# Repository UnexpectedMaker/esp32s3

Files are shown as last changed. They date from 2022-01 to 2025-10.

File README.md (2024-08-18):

# Unexpected Maker - ESP32-S3 Boards 

Assorted files for my ESP32-S3 development boards 













You can find out more about my ESP32-S3 boards at https://esp32s3.com 

# Contents
In this repo you'll find the following items:

## 3D Models
3D STEP files for each of the OMGS3, NanoS3, TinyS3, ProS3 and FeatherS3 boards

## KiCAD 6/7/8 Symbols
KiCAD 6 symbol files for each of the boards that you can use when integrating one of them into one of your PCB designs.
NanoS3 symbol file is for KiCAD 7 or later
OMGS3 symbol file is for KiCAD 8 or later

## KiCAD 6/7 Footprints	
KiCAD 6 footprint files for each of the boards including both SMD and TH versions for the ProS3
NanoS3 footprint file is for KiCAD 7 or later
OMGS3 footprint file is for KiCAD 8 or later

## Schematics
PDF Schematics for each of the OMGS3, NanoS3, TinyS3, ProS3 and FeatherS3 boards

## Pin Reference Cards
Hires pinout reference cards for each of the OMGS3, NanoS3, TinyS3, ProS3 and FeatherS3 boards

# Support Unexpected Maker

I love designing, making, and releasing projects and products that empower others to learn and build amazing things! I do it because I believe it’s important to share knowledge and give back to the community as many have done before me. It helps us all learn and grow.

Please consider supporting me by buying some of my products from:

https://unexpectedmaker.com/shop

Or by buying one of my products on tindie or Lectronz:

https://www.tindie.com/stores/seonr/
https://lectronz.com/stores/unexpectedmaker

Or by becoming a Patron:

https://www.patreon.com/unexpectedmaker

## Unexpected Maker
http://youtube.com/c/unexpectedmaker

http://twitter.com/unexpectedmaker

https://discord.gg/xAHpApP

https://www.facebook.com/unexpectedmaker/

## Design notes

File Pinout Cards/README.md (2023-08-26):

# Pinout Cards - Unexpected Maker - ESP32-S3 Boards 
Hires pinout cards for my ESP32-S3 boards  

You can find out more about my ESP32-S3 boards at https://esp32s3.com 

Artwork and content in this folder is © 2022,2023 Unexpected Maker, all rights reserved.

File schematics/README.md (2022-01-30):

# Schematics - Unexpected Maker - ESP32-S3 Boards 
PDF Schematics for my ESP32-S3 boards  

You can find out more about my ESP32-S3 boards at https://esp32s3.com 

Please refer to the included license.

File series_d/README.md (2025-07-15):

# Unexpected Maker - Series[D]



Assorted files for my new ESP32-S3 Series[D] development boards 









You can find out more about my ESP32-S3 boards at https://esp32s3.com

# Contents
In this repo you'll find the following items:

## 3D Models
3D STEP files for each of the TinyS3[D], ProS3[D], FeatherS3[D] and EdgeS3[D] boards

You'll also find a STEP file for the EdgeS3[D] Reference Carrier board and a STEP for the M.2 connector footprint with the EdgeS3[D] inserted to help line things up.

## Schematics
PDF Schematics for each of the TinyS3[D], ProS3[D], FeatherS3[D] and EdgeS3[D] boards.

## KiCAD (v9)
Symbol and Footprint for EdgeS3[D] and a project folder for the EdgeS3[D] Reference Carrier PCB.

## Pin Reference Cards
Hires pinout reference cards for each of the TinyS3[D], ProS3[D], FeatherS3[D] and EdgeS3[D] boards

# Support Unexpected Maker
I love designing, making, and releasing projects and products that empower others to learn and build amazing things! I do it because I believe it’s important to share knowledge and give back to the community as many have done before me. It helps us all learn and grow.

Please consider supporting me by buying some of my products from:

https://unexpectedmaker.com/shop

Or by buying one of my products on tindie or Lectronz:

https://www.tindie.com/stores/seonr/
https://lectronz.com/stores/unexpectedmaker

Or by becoming a Patron:

https://www.patreon.com/unexpectedmaker

## Unexpected Maker
http://youtube.com/c/unexpectedmaker

http://twitter.com/unexpectedmaker

https://discord.gg/xAHpApP

https://www.facebook.com/unexpectedmaker/

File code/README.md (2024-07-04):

# Code - Unexpected Maker - ESP32-S3 Boards 
Code examples and helper libraries for ESP32-S3 boards

Currently includes:

## CircuitPython
- Shipping files including the CP helper library and code.py

## MicroPython
- Helper library and example code

## Arduino
- A link to the Helper library and example code for the Arduino IDE, to be installed via the library manager 

## PlatformIO
- An example project setup for the FeatherS3 that uses the UM S3 Helper Arduino library to cycle the RGB LED, flash the Blue LED and print out an RGB cycle count to the serial console. 

You can find out more about my ESP32-S3 boards at https://esp32s3.com 

Please refer to the included license.

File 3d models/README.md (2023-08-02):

# 3D models - Unexpected Maker - ESP32-S3 Boards 
3D STEP models and reference images of my ESP32-S3 boards  

You can find out more about my ESP32-S3 boards at https://esp32s3.com 

Artwork and content in this folder is (c)2022,2023 Unexpected Maker, all rights reserved.

### NanoS3
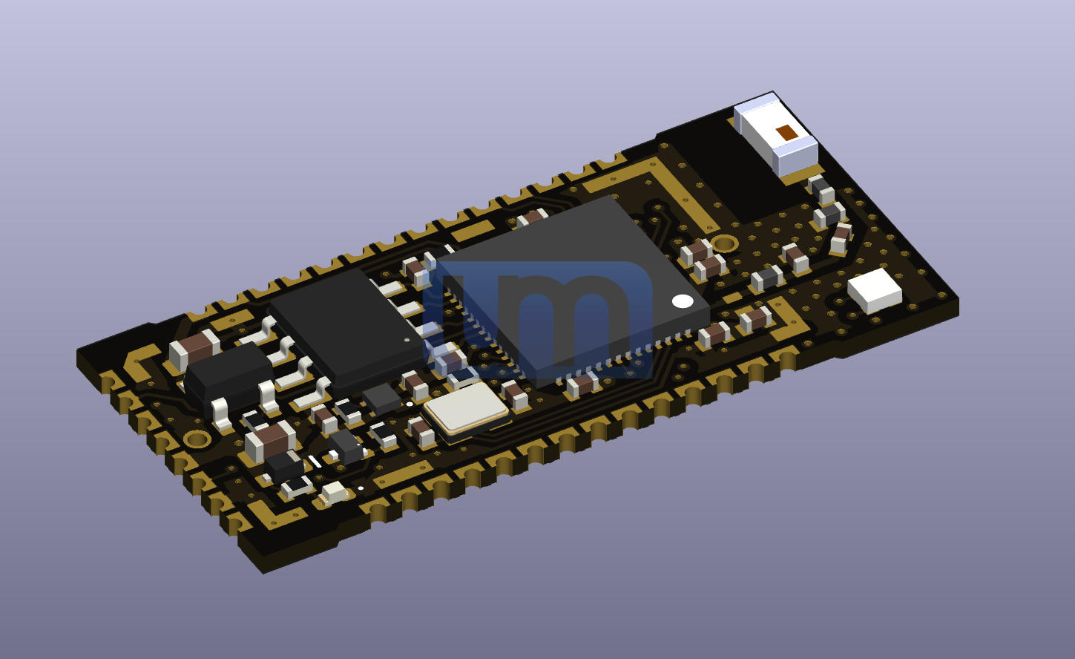
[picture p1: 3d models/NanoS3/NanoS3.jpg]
NanoS3


### TinyS3 & TinyS3 uFL
<div>
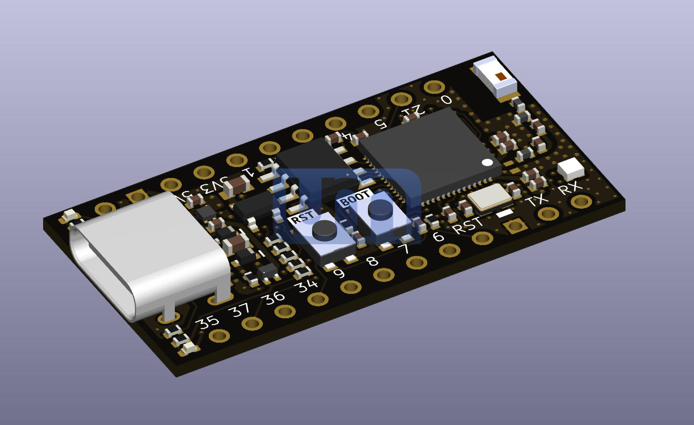
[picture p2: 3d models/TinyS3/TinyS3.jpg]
TinyS3
    
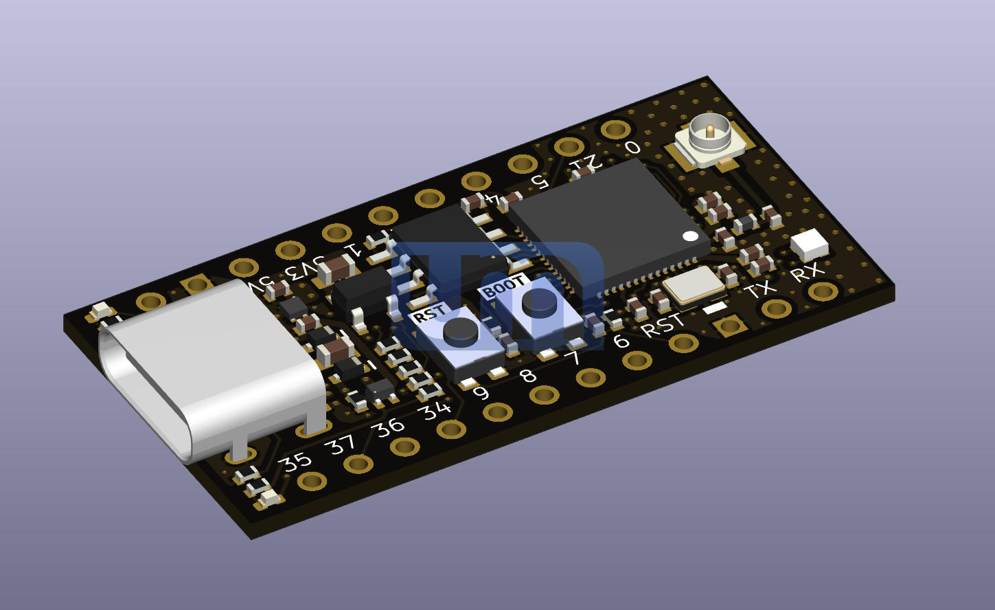
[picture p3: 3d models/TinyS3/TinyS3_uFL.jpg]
TinyS3 uFL
    
</div>

### ProS3 & ProS3 uFL
<div>
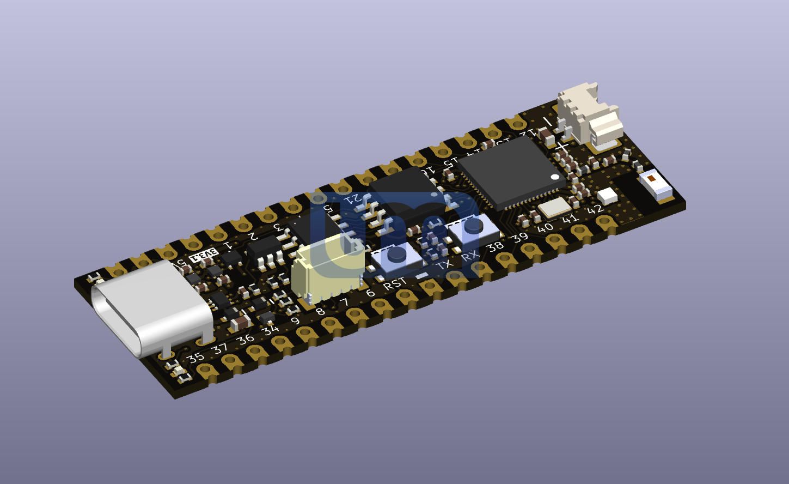
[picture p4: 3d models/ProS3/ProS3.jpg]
ProS3
    
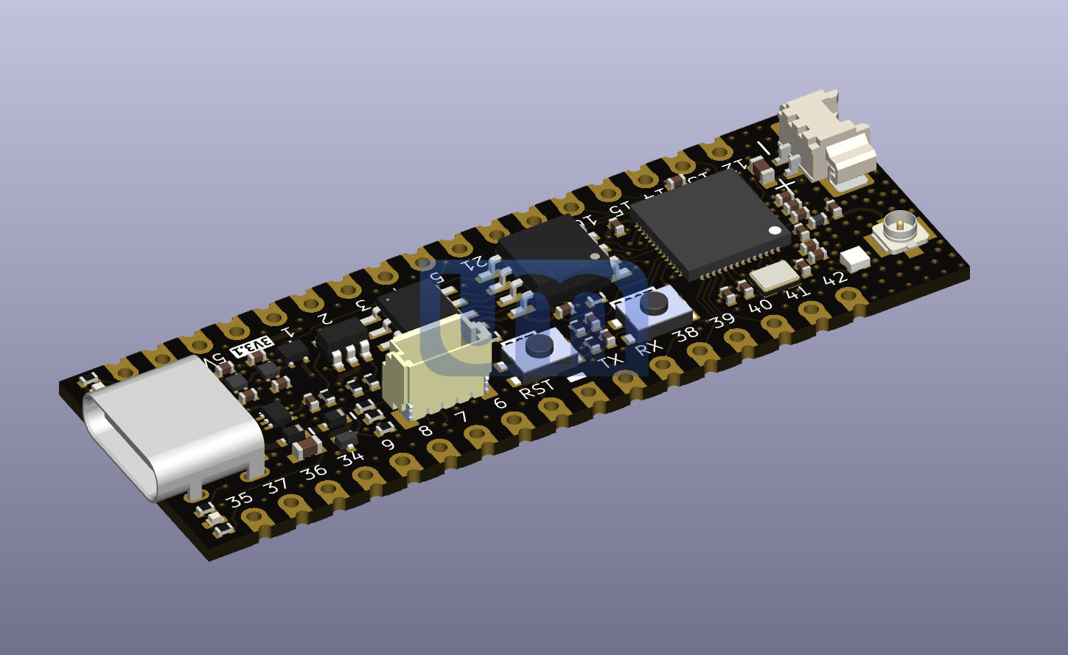
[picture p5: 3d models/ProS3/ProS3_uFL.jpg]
ProS3 uFL
    
</div>

### FeatherS3 & FeatherS3 uFL
<div>
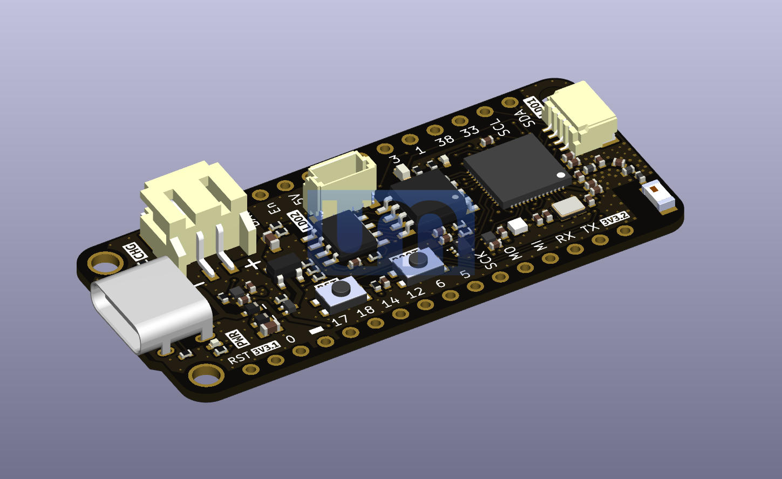
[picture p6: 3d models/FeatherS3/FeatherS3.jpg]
FeatherS3
    
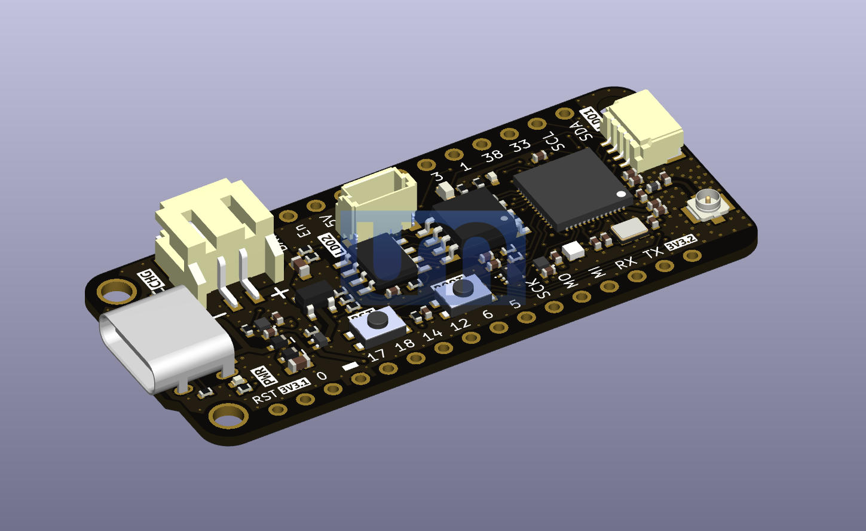
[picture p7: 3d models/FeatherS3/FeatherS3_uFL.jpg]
FeatherS3 uFL
    
</div>

### NanoS3 Carrier
<div>
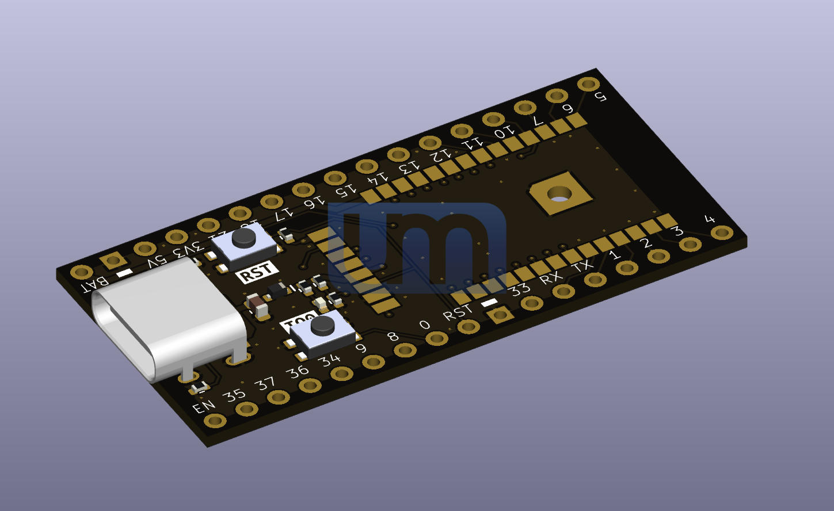
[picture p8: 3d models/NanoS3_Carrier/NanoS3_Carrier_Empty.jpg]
NanoS3 Carrier Empty
    
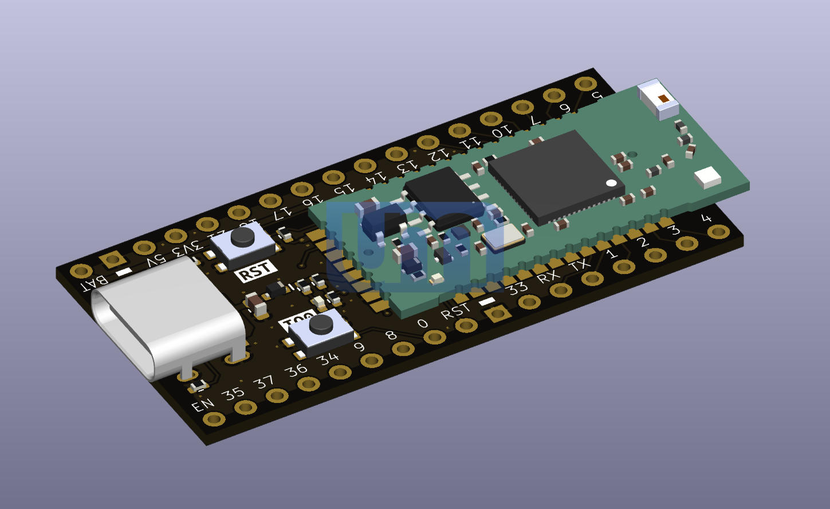
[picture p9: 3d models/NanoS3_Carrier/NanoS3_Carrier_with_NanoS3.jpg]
NanoS3 Carrier with NanoS3
    
</div>

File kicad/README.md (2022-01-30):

# KiCAD Footprints - Unexpected Maker - ESP32-S3 Boards 
KiCAD Footprints for my ESP32-S3 boards  

You can find out more about my ESP32-S3 boards at https://esp32s3.com 

Please refer to the included license.

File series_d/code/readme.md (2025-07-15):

# Code - Unexpected Maker - Series[D] Boards 
Code examples, shipping files and helper libraries for Series[D] boards

Currently includes:

## CircuitPython
Shipping files includes the Circ uitPython helper library and code.py, for each board, plus a `lib` folder populated with the requirements for the `Adafruit MAX17048` Battery FG IC library.

CircuitPython support for EdgeS3[D] (that the EdgeS3[D] ships with) has been PR'd and merged into the CircuiPython repo for a future release.

There are no Series[D] board specific CircuitPython builds for TinyS3[D], ProS3[D] and FeatherS3[D] - They use their origional non Series[D] board CircuitPython builds.

Due to this, not every IO used on a Series[D] board is available in the `boards` import, but all IO can be accessed using `microcontroller.pin`, for example, to access IO11 on the ProS3 buildind running on the ProS3[D], you use the following syntax:

``` python
# Setup the RF switch pin
ant_selection = DigitalInOut(microcontroller.pin.GPIO11)
ant_selection.direction = Direction.OUTPUT
```

## MicroPython
MicroPython builds for TinyS3[D], ProS3[D] and FeatherS3[D] use the origional TinyS3, ProS3 and FeatherS3 builds available at [micropython.org](https://micropython.org/download/?vendor=Unexpected%20Maker)

Helper libraries and example code wil be available soon.

## Arduino
Check the Arduino folder for a link to the Series[D] Helper library and example code for the Arduino IDE, to be installed via the library manager 

## PlatformIO
Soon!

You can find out more about my Series[D] boards at https://esp32s3.com 

Please refer to the included license.

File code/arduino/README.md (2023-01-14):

# Unexpected Maker ESP32-S3 Arduino Helper Library

This is the [helper library](https://github.com/UnexpectedMaker/esp32s3-arduino-helper) for all the Unexpected Maker [ESP32-S3 boards](https://esp32s3.com).

Examples can be found in the [examples directory](https://github.com/UnexpectedMaker/esp32s3-arduino-helper/tree/main/examples), these can also be loaded from the examples menu in the Arduino IDE.

## Installation

Please download the library called `UMS3 Helper` via the Arduino Library Manager.

## List of functions

```c++

// Initializes all UM board peripherals
void begin();

// Set LDO2 on or off (ProS3 and FeatherS3 only)
void setLDO2Power(bool on);

// Set neopixel power on or off (On ProS3 and Feather it sets LDO2 on)
void setPixelPower(bool on);

// Set neopixel color
void setPixelColor(uint8_t r, uint8_t g, uint8_t b);
void setPixelColor(uint32_t rgb);

// Set neopixel brightness
void setPixelBrightness(uint8_t brightness);

// Pack r,g,b (0-255) into a 32bit rgb color
static uint32_t color(uint8_t r, uint8_t g, uint8_t b);

// Convert a color wheel angle (0-255) to a 32bit rgb color
static uint32_t colorWheel(uint8_t pos);

// Set the blue LED on or off (FeatherS3 only)
void setBlueLED(bool on);

// Toggle the blue LED (FeatherS3 only)
void toggleBlueLED();

// Get the battery voltage in volts
float getBatteryVoltage();

// Get the light sensor in volts (0-3.3)
float getLightSensorVoltage();

// Detect if VBUS (USB power) is present
bool getVbusPresent();
```

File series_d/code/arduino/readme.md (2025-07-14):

# Unexpected Maker ESP32-S3 Arduino Helper Library

This is the [helper library](https://github.com/UnexpectedMaker/seriesd_arduino_helper) for all the Unexpected Maker [Series[D] boards](https://esp32s3.com).

Examples can be found in the [examples directory](https://github.com/UnexpectedMaker/seriesd_arduino_helper/tree/main/examples), these can also be loaded from the examples menu in the Arduino IDE.

Examples include switching ANtenna output, Reading the battery, controlling the RGB LED (if one is present on the board)

## Installation

Please download the library called `UM Series[D] Helper` via the Arduino Library Manager.

## List of functions

```c++

// Initializes all UM Series[D] board peripherals
void begin();

// Set LDO2 on or off
// Only available on the ProS3[D] and FeatherS3[D] 
void setLDO2Power(bool on);

// Set RGB LED power on or off (On ProS3[D] and FeatherS3[D] it sets LDO2 on)
// Not available on the EdgeS3[D] 
void setPixelPower(bool on);

// Set RGB LED color
// Not available on the EdgeS3[D] 
void setPixelColor(uint8_t r, uint8_t g, uint8_t b);
void setPixelColor(uint32_t rgb);

// Set RGB LED brightness
// Not available on the EdgeS3[D] 
void setPixelBrightness(uint8_t brightness);

// Pack r,g,b (0-255) into a 32bit rgb color
static uint32_t color(uint8_t r, uint8_t g, uint8_t b);

// Convert a color wheel angle (0-255) to a 32bit rgb color
static uint32_t colorWheel(uint8_t pos);

// Set the blue LED on or off
// Only available on the FeatherS3[D]
void setBlueLED(bool on);

// Get the light sensor in volts (0-3.3)
// Only available on the FeatherS3[D]
float getLightSensorVoltage();

// Toggle the blue LED
// Only available on the FeatherS3[D]
void toggleBlueLED();

// Get the battery voltage in volts
// This function gets the voltage from the MAX17048
float getBatteryVoltage();

// Detect if VBUS (USB power) is present
// Not available on the EdgeS3[D] 
bool getVbusPresent();

// Set the RF Switch to external antenna
void setAntennaExternal(bool state);
```

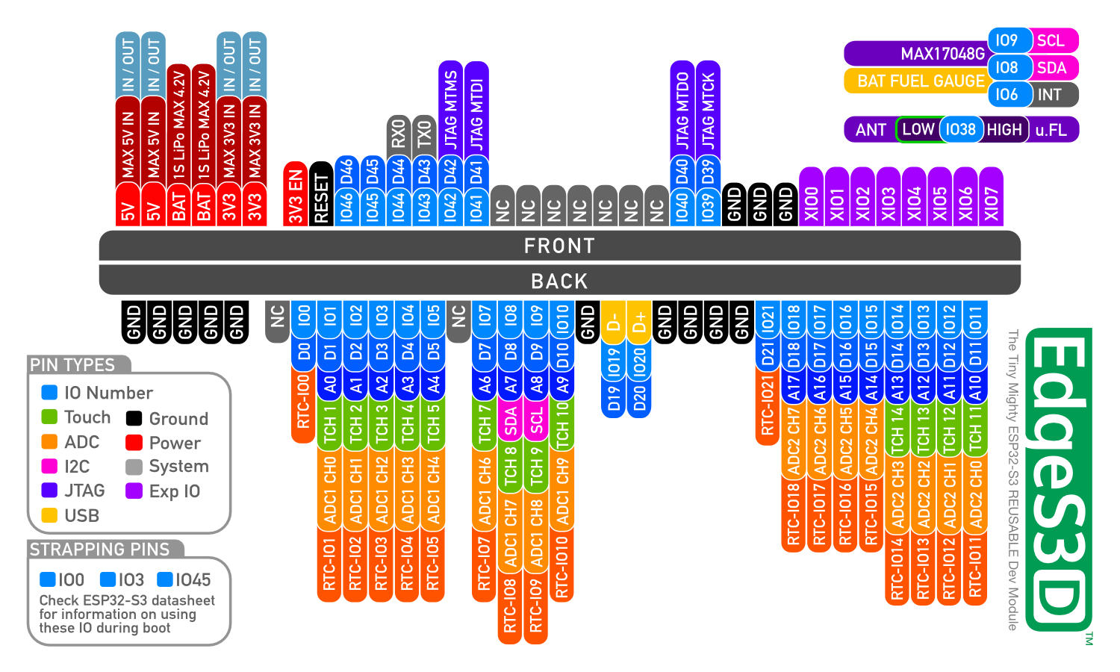
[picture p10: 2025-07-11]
series_d/pinout_cards/edges3d_pinout.jpg

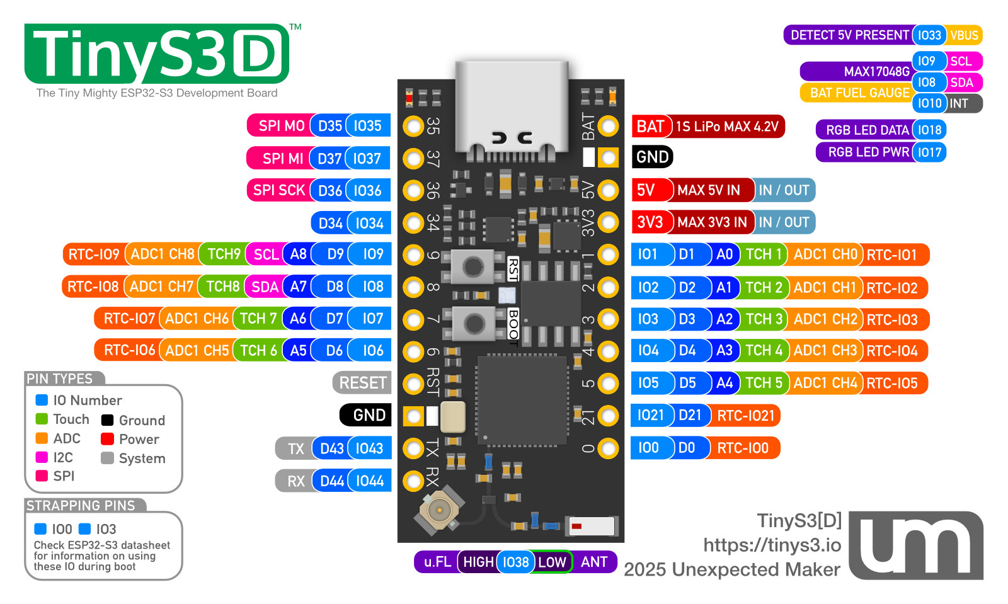
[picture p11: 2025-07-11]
series_d/pinout_cards/tinys3d_pinout.jpg

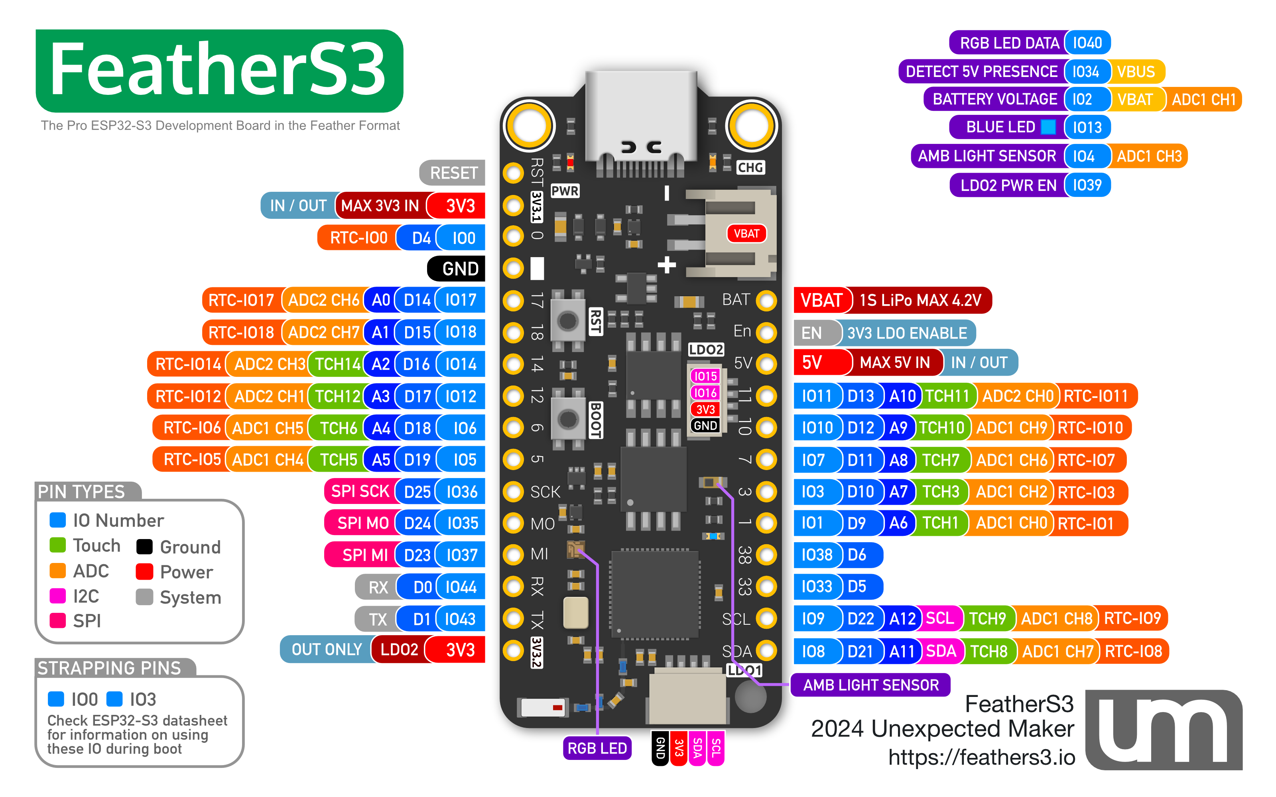
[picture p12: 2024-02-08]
Pinout Cards/FeatherS3_Pin_Reference.png

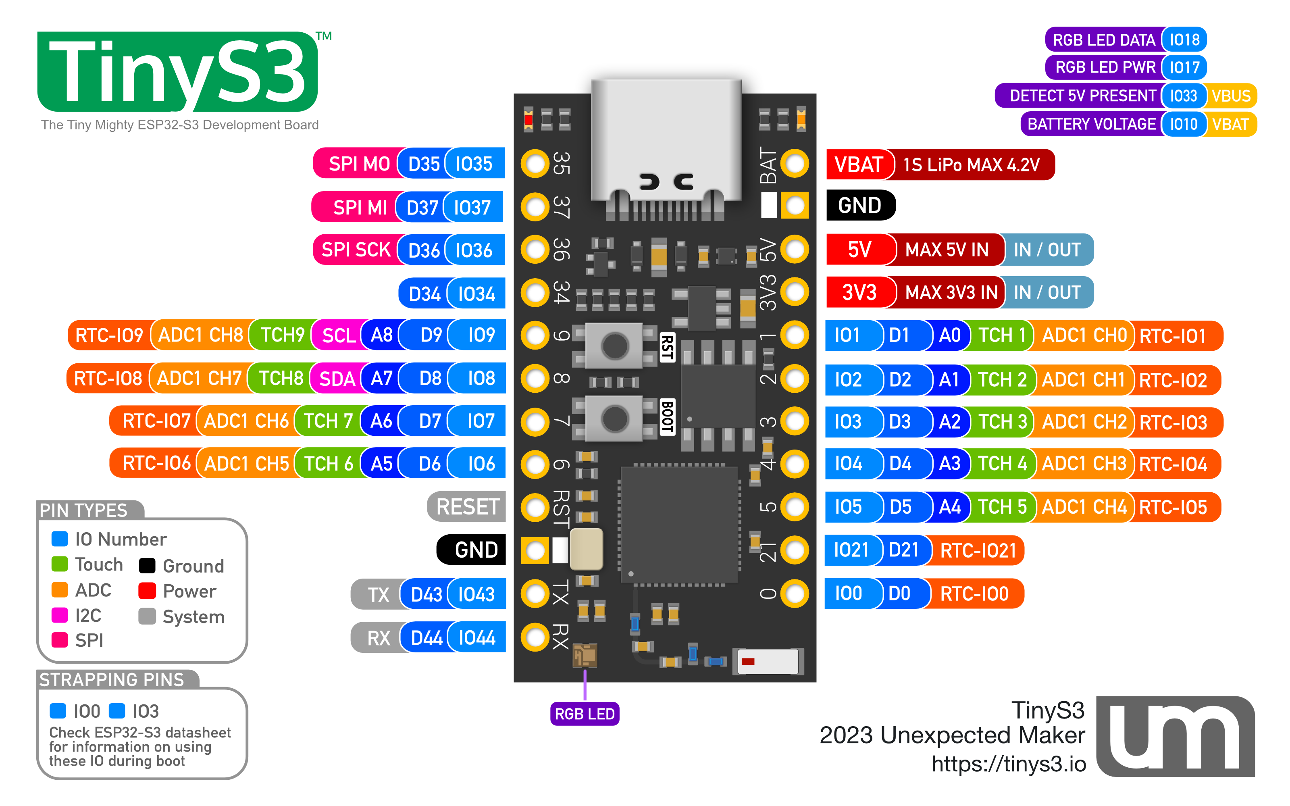
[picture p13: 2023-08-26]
Pinout Cards/TinyS3_Pin_Reference.png

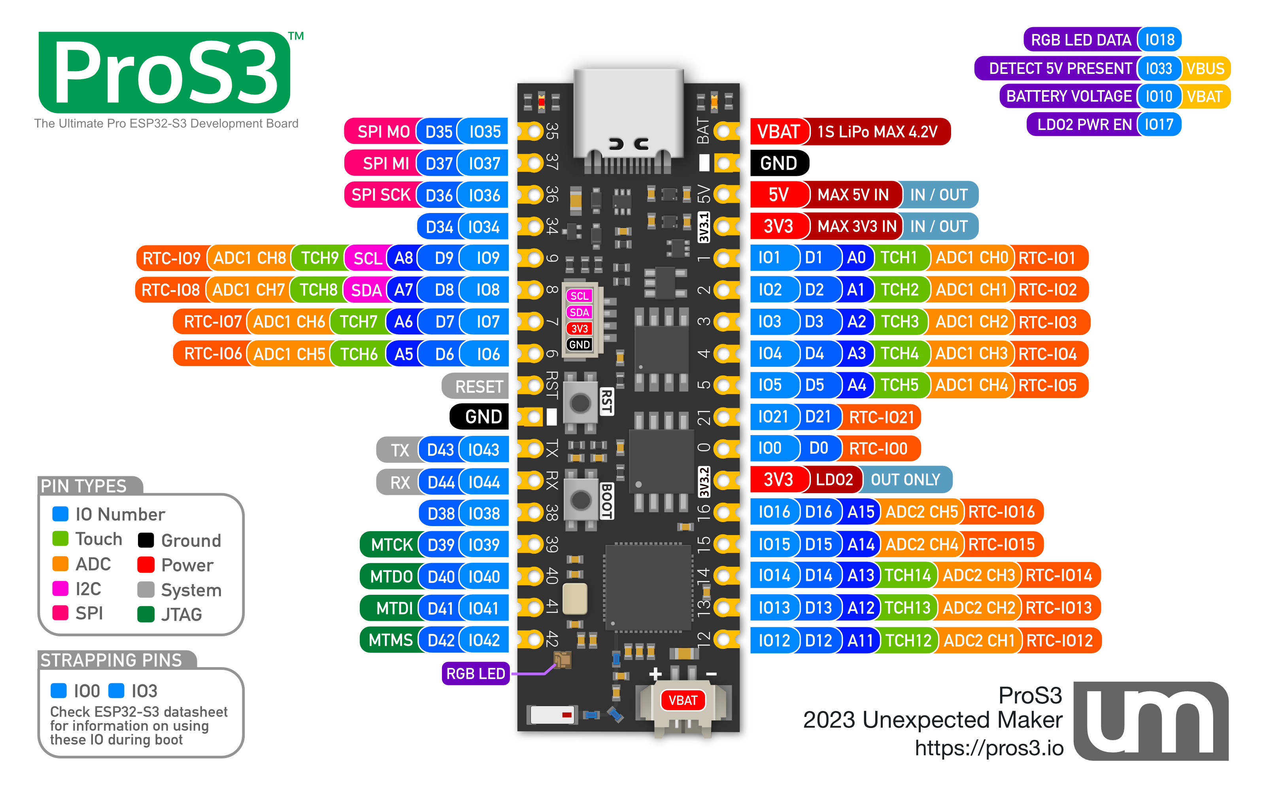
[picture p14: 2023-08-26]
Pinout Cards/ProS3_Pin_Reference.png

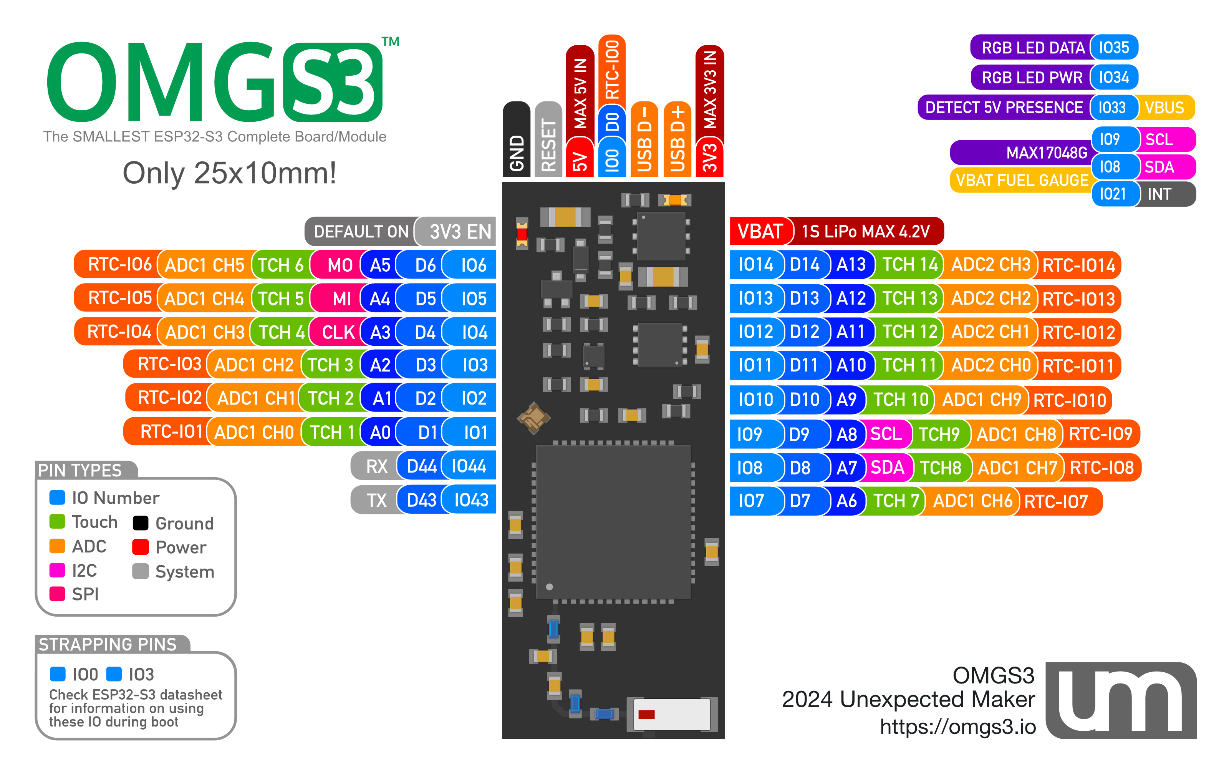
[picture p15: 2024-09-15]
Pinout Cards/OMGS3_Pin_Reference.png

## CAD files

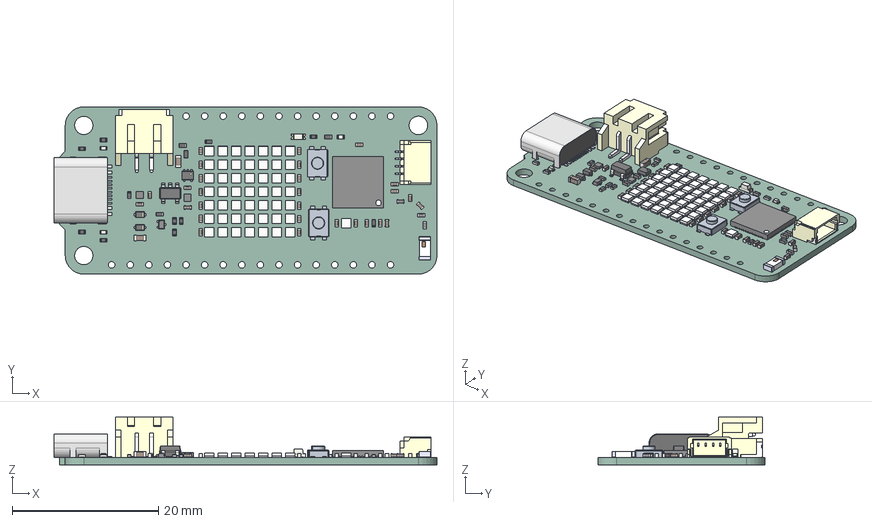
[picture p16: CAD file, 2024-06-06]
3d models/FeatherS3Neo/FeatherS3Neo.step
52.3 x 22.9 x 6.55 mm
2450AT18B100E
D_SOD_523 x 2
LED_0402_1005Metric x 3
R_0402_1005Metric x 15
C_0402_1005Metric x 28
SOT_23_5
ESD7C5.0DT5G
APA102 2020 LED v2 x 50
BTN_KMR2_4.6X2.8_HAND v1 x 2
HRO USB-C col 3 v9
LED_0805_2012Metric_Castellated
ESP32-S2
L_0402_1005Metric x 3
C_0603_1608Metric x 2
SM04B-SRSS-TB(LF)(SN)
NCP160AMX280TBG x 2
S2B-PH-SM4-TB(LF)(SN)
SOT_553
FeatherS3 Neo_PCB

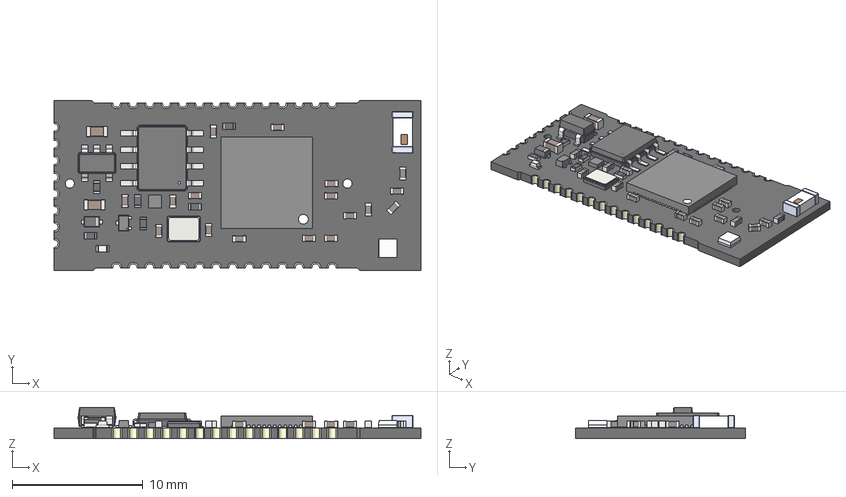
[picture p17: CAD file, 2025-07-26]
3d models/NanoS3/NanoS3 Castellated.step
28.1 x 13.0 x 2.40 mm
NanoS3_2450AT18B PCB

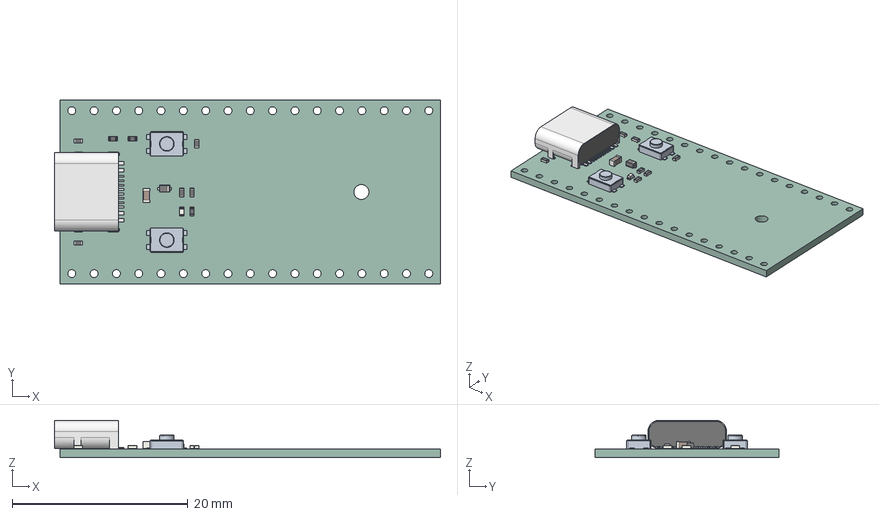
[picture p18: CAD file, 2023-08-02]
3d models/NanoS3_Carrier/NanoS3_Carrier_Empty.STEP
43.9 x 21.0 x 4.24 mm
_autosave-NanoS3_Carrier PCB

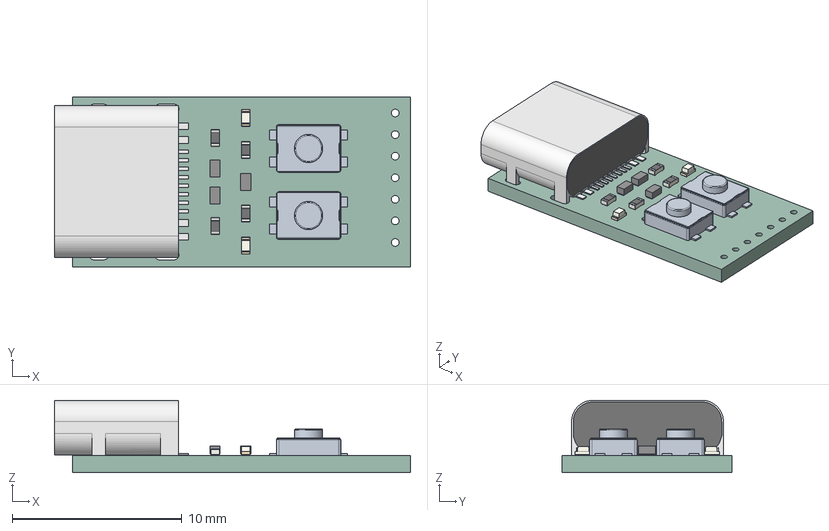
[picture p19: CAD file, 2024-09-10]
3d models/OMGS3/OMGUSB.step
21.0 x 10.0 x 4.26 mm
R_0402_1005Metric x 4
BTN_KMR2_4.6X2.8_HAND v1 x 2
HRO USB-C col 3 v9
TESD5V0L1UC RJG x 3
LED_0402_1005Metric x 2
OMGUSB_P3_PCB

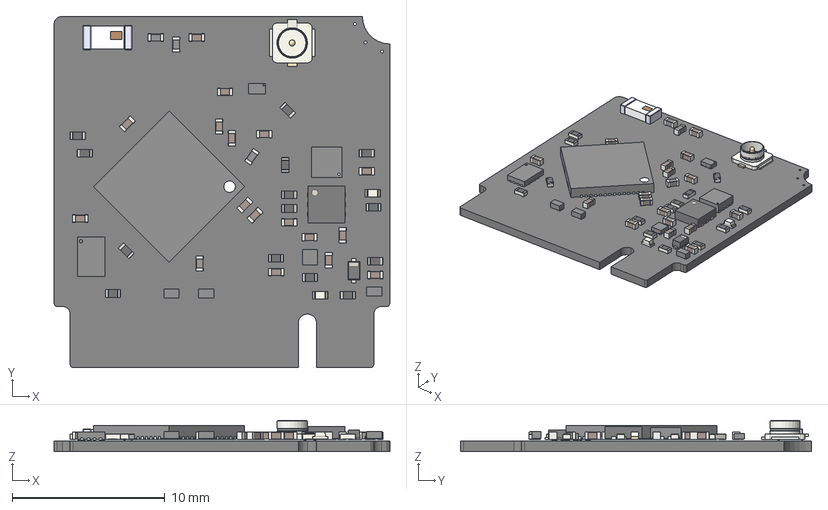
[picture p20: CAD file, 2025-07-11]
series_d/3d models/EdgeS3D.step
22.0 x 23.0 x 2.05 mm
C_0402_1005Metric x 17
U.FL_Hirose_U.FL-R-SMT-1_Vertical
BGS12WN6E6327XTSA1
L_0402_1005Metric x 3
R_0402_1005Metric x 14
TVS_DFN1006 x 3
LED_0402_1005Metric x 2
NCP170AMX170TCG
FXL6408UMX
D_SOD-523
2450AT18B100E--3DModel-STEP-269445
TDFN-6-1EP_2.5x2.5mm_P0.65mm_EP1.3x2mm
MAX17048G-T10
ESP32_S2--3DModel-STEP-1
EdgeS3_Dual_R1_PCB

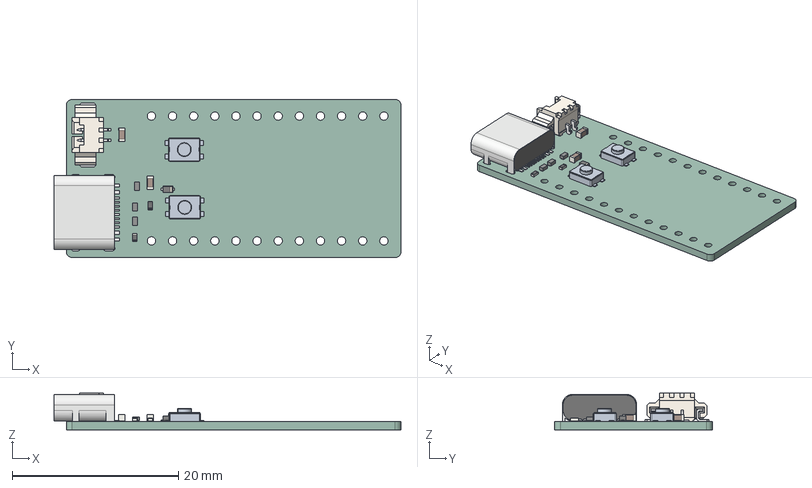
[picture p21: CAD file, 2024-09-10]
3d models/OMGS3/OMGS3_Carrier.step
41.7 x 19.0 x 4.40 mm
C_0603_1608Metric x 2
PICOBLADE v1
BTN_KMR2_4.6X2.8_HAND v1 x 2
R_0402_1005Metric x 2
TESD5V0L1UC RJG x 3
HRO USB-C col 3 v9
D_SOD_523
OMGS3_Carrier_R1_PCB

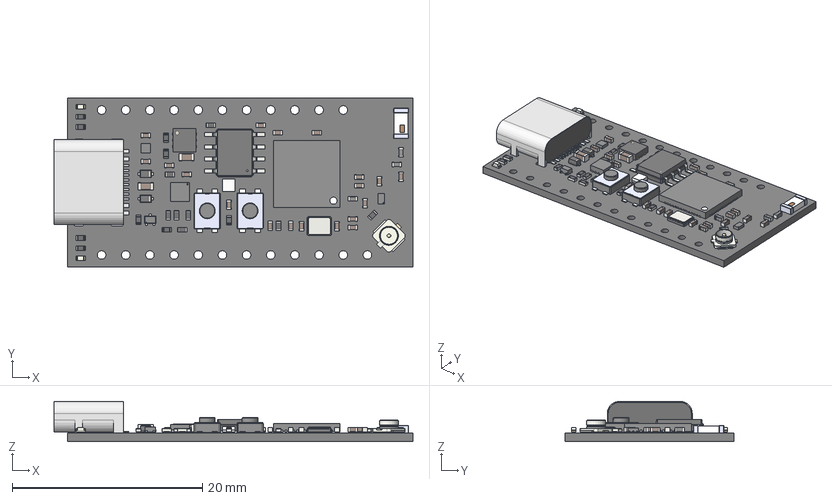
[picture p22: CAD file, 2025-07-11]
series_d/3d models/TinyS3D.step
37.7 x 17.8 x 4.21 mm
R_0402_1005Metric x 17
C_0402_1005Metric x 19
TDFN-6-1EP_2.5x2.5mm_P0.65mm_EP1.3x2mm
L_0402_1005Metric x 3
KMR221GLFS--3DModel-STEP-56544 v3 x 2
U.FL_Hirose_U.FL-R-SMT-1_Vertical
BGS12WN6E6327XTSA1
LED_0402_1005Metric x 2
MAX17048G-T10
SOT-723
NCP170AMX170TCG
D_SOD-523 x 2
SSOP-8_3.9x5.05mm_P1.27mm
2450AT18B100E--3DModel-STEP-269445
Crystal_SMD_3225-4Pin_3.2x2.5mm_HandSoldering
C_0603_1608Metric x 2
ESP32_S2--3DModel-STEP-1
HIRO-USB-C Fixed Position
TinyS3D_P1_PCB

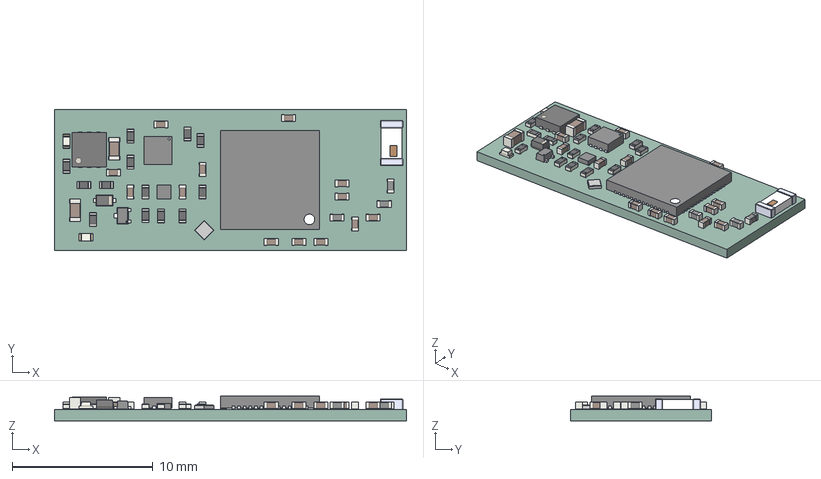
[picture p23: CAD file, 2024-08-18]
3d models/OMGS3/OMGS3.step
25.0 x 10.0 x 1.75 mm
C_0402_1005Metric x 13
L_0402_1005Metric x 3
R_0402_1005Metric x 13
(Unsaved)
TDFN_6_1EP_25x25mm_P065mm_EP13x2mm
2450AT18B100E
LED_0402_1005Metric x 2
MAX17048G+T10
ESD7C5.0DT5G
NCP160AMX280TBG
D_SOD_523
C_0603_1608Metric x 2
ESP32-S2
_autosave-OMGS3_P1_1.27_PCB

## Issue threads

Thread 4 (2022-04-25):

FeatherS3 Pin clarification required from datasheet

sukesh-ak, 2022-04-25:
Are the 2 Stemma QT connectors using the same PINS?

I am trying to use one of them for UART and one for I2C.
Also the labels for Vertical connector is mixed up.

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

UnexpectedMaker, 2022-04-25:
Stemma is only I2C. Yes they share the same I2C pins.

UnexpectedMaker, 2022-04-25:
These are questions for my discord server. Please join there.

Closed 2022-04-25.

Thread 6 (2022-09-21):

404 not found code from link in readme

devoh747, 2022-09-21:
from the readme(https://github.com/UnexpectedMaker/esp32s3/tree/main/code/arduino) "example files"  https://github.com/UnexpectedMaker/esp32s3/blob/main/code/arduino/examples  gives a 404 error as it doesn't exist.

UnexpectedMaker, 2022-09-21:
Fixed, thanks!

Closed 2022-09-21.

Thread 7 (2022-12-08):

D5?

gwolber, 2022-12-08:
Hi, I really love the s3tiny, congratulations on this great work!
However, I encountered a problem: After connecting 5V to the USB power pin on the breakout header, my board cannot be powered over the USB port anymore; D5 seems dead for whatever reason. Could you tell me which type of Z-Diode D5 exactly is? Or is there even a parts list that I did not find?
Thanks, Gerhard

UnexpectedMaker, 2022-12-08:
Oh no! Are you sure you didn't short the pins somehow? You should be able to have the USB connected and the 5V rail connected to external power at the same time.  That's what the back feed diode is there for.
Anyhow, it's a 1A SOD523 Schottky diode, not a Zenner. Any 1A  Schottky will do if you plan on replacing it.

gwolber, 2022-12-09:
Great, thanks!! :)

Closed 2022-12-09.

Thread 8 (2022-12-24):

Backward pins in KiCAD schematic lib for FeatherS3 and TinyS3

username115, 2022-12-24:
All of the pins in the KiCAD schematic library for the FeatherS3 an TinyS3 are backwards. In KiCAD, the little circle is used as the attachment point, and it should be facing outward. Also, the pin labels should be internal to the part.

The ProS3 has its pins in the correct orientation

UnexpectedMaker, 2022-12-24:
That's been fixed, thanks very much for spotting this!

Closed 2022-12-24.

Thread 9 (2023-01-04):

unreliable boot behavior on power up

rottaran, 2023-01-04:
We encountered a timing glitch with one UM FeatherS3 boards. In our hardware, we switch the system on by releasing the Feather's EN pin. Then, quite often the FeatherS3 boots into booloader mode as if the BOOT button was pressed or IO0 pulled to ground. On the oscilloscope it is visible, that the ESP32-S3 chip begins to boot, then activates the internal pullup on IO0. It seems that the voltage is up too late on IO0.

We solved this by adding a 470k resistor from IO0 to 3.3V. Now booting behaves properly.
A larger 4.7uF capacitor from RST to ground did not seem to help.

Is this a known issue? It also never appeared when combined with the Feather OLED Display.

UnexpectedMaker, 2023-01-04:
Are you sure it's not IO47 (SPICLK_P) that's triggering the "enter UF2 bootloader mode" ? It's designed to allow for a double reset press to get into UF2 mode. This is part of the UF2 bootloader code.

Otherwise, it could just be a timing thing, and your fix of putting a weak pull-up on IO0 is the correct solution. I leave IO0 floating by design (the recommended implementation by Espressif) and it's a strapping pin and should not be influenced at boot time, but in your case, the pull-up is fine.

A larger cap on RESET wont make any difference, as the RESET pin on the ESP32 is actually an EN pin, so until EN is high, the ESP32 is off, and therefore wont start to influence IO0. So even a 100000uF cap wont help there ;)

rottaran, 2023-01-13:
Thanks for the feedback! In that case, everything works as designed.

rottaran, 2023-03-03:
Sorry, it's our fault. Due to running out of pins, I attached an 1-wire temperature sensor to the BOOT IO0 pin and forgot the required 4.7k pull-up. Thus, the sensor was delaying the voltage rise during boot and confused the microcontroller.

Closed 2023-01-13.

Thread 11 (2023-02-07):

WiFi stopped working from nowhere

JPZV, 2023-02-07:
Hi! I love this board, and I'm making a smart Xylobands with a fork of [WLED](https://github.com/Aircoookie/WLED/). I don't like the TinyS3 to be very hot while using WiFi so I turn it off after a minute because it's not needed for my project, except for the initial setup.

But right now I have a problem because the WiFi doesn't works at all, and the board overheats a lot, specially with the USB connected (using the Battery will make the board overheat but not that much). At the morning it was working correctly, but from nowhere it stopped to do.

WLED uses the AP Mode, and it doesn't shows up neither on my computer nor on my phone. I also tested a example project from Arduino-esp32 which connects to my network and it also fails (it tries to connect to my network infinitely while another ESP32 would connect almost intermediately)

What can I do? There is no error message apparently so I don't have any clue

~~PS: Viewing the datasheet, there is a capacitor named C5, but on my board that seems to be a resistor, which also is in short (i.e. It has continuity between its terminals). Is it normal? Or is it fried somehow?~~ After viewing the datasheet for others type of ESP32, it seems to be normal to have a zero ohms resistor between the antenna and the ESP32

UnexpectedMaker, 2023-02-08:
Can you join my discord server and post for help in there in the `#um-hardware` help section? That's the best place to get support from me and others in the community.
https://discord.gg/xAHpApP

Thanks :)

Closed 2023-02-08.

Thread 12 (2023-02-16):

Micropython Helper Libraries - get_battery_voltage() results not usable

Hamsanger, 2023-02-16:
Using Micropython V1.19.1+, the implementation of the battery monitor on GPIO2 and get_battery_voltage() produces invalid results.  The default range of the ADC with attenuation of 0dB is only 850mV (refer to the ADC Characteristics in the ESP32-S3 datasheet), so the voltage presented to the ADC from the voltage divider on GPIO2 saturates the count for any usable LiPo voltages unless some input attenuation is used.

I have obtained good results using ATTN_2_5DB and the newer ADC.read_uv() function while scaling the voltage reading using the voltage divider resistor values.  For a FeatherS3 board, the code looks similar to:

```py
# Battery voltage divider.  Voltage seen by the ADC is VBAT * R1 / (R1 + R2)
R1 = 160 # voltage divider R1 in kOhms
R2 = 442 # voltage divider R2 in kOhms

vbat_scale_factor = (R1 + R2) / R1 / 1_000_000 # to convert the microvolt reading to volts

def get_battery_voltage():
    """
    Returns the current battery voltage. If no battery is connected, returns around 4.2V which is the charge voltage
    This is an approximation only, but useful to detect if the charge state of the battery is getting low.
    """
    adc = ADC(Pin(VBAT_SENSE), atten=ADC.ATTN_2_5DB) # Assign the ADC pin to read with nominal 0..1.1V range
    # We are going to read the ADC 10 times and discard the results as we can't guarantee the ADC is calibrated or stable yet after boot. Not sure why we have to do this :(
    for _ in range(10):
        adc.read()
    measuredvbat = adc.read_uv() * vbat_scale_factor
    return round(measuredvbat, 2)
```
As the voltage scaling factor is derived from first principles, the values of R1 and R2 shown can be adjusted to suit other designs.

ShayBox, 2023-07-04:
How does this compare to the current version, it seems to have changed to not use `ADC()`

anglerfish27, 2023-09-28:
FYI. I've used the built in examples with firmware 1.20 (current supported release not the nightly build). It works fine for me. The voltage of the battery when polled is exactly the voltage reading I get from a benchtop multi meter. So if the board says my Lipo battery is at 3.1V I disconnect and check it indeed its right on at 3.1xxxxxx Volts. I'm not doing anything special except running 1.20 official release of MP from their website. Good luck.

I found this to be a very hand feature so I can shutdown the MCU workload when the battery reaches what I decide is too low for that particular set of Lipo 18650's based on manufacturer specs.  Best of luck. Seems to work fine for me. ::shrug::

Closed 2025-08-24.

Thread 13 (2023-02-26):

External Anntena ProS3

osorioen, 2023-02-26:
Hi. I need to connect a external antenna to ProS3 . How can I do it?

UnexpectedMaker, 2023-02-26:
It's not really possible. Even taking off the SMD antenna won't allow you to attach an external antenna.

UnexpectedMaker, 2023-05-11:
Just wanted to let you know I've released new S3 boards with u.FL connectors....
https://unexpectedmaker.com/shop/pros3-ufl

Closed 2023-08-03.

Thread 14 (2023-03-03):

FeatherS3 pins for external 32.768kHz crystal

rottaran, 2023-03-03:
While doing experiments with BLE on battery power, we noticed an unexpectedly high current consumption. This makes the battery connector on the board less useful. With dynamic frequency scaling, modem-sleep and CPU pause, we got down to 25mA average. In order to get to the 2 to 5mA light-sleep mode with running BLE connections, it is necessary to connect a 32.768kHz crystal and respective load capacitors to the XTAL_32K pins.

Sadly, the XTAL_32K seem to be not connected on anything on the UM Feather S3. Maybe it could be a nice feature for future products to at least have unpopulated footprints for the crystal and capacitors on the bottom side of the board.

UnexpectedMaker, 2023-08-03:
Sorry I didn't get around to answering this already :(
IO15/16 that are used for hooking up an external 32K Xtal are already in use on the second STEMMA/QT connector as I2C bus 2, sorry.

rottaran, 2023-08-05:
No problem. I was unaware of the change back then. Seems sensible to separate both I2C busses. Out of curiosity, what speaks against using IO17/IO18 or IO45/IO46 for the STEMMA2 connector?

UnexpectedMaker, 2023-08-06:
Well, IO46 is a strapping IO, so not usable, but ultimately, nothing wrong with other IO for STEMMA2 - but 15/16 is what I chose and it can't be changed now as it's a released design with supporting firmware that initialises those pins as STEMMA/QT #2.

I do custom design works for people needing alterations on my designs - if an external 32k Xtal is something you'd like and it's something you require in quantity, I'm happy to chat about it.

Closed 2023-08-09.

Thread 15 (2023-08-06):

connector lost (LDO2)

CrackXT, 2023-08-06:
Some thing is missing ;)
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

UnexpectedMaker, 2023-08-06:
Fixed, thanks very much :)

Closed 2023-08-06.

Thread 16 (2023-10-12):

Error in schematic ?

eleroy, 2023-10-12:
Hi,

Thank you for your boards, I love them.

I wonder if there is an error in the schematic [here](https://github.com/UnexpectedMaker/esp32s3/blob/main/schematics/schematic-tinys3.pdf).

I'm not the best at electronics but isn't The P-mos T3 used for switching off the battery when connecting the USB upside down ?

Usually for a P-mos, the current is meant to flow from source to drain.

Best,

Edouard.

UnexpectedMaker, 2023-10-12:
The schematic for the power section may look unconventional, but it is correct :)

eleroy, 2023-10-17:
Ah yes, I got it, thanks.

Closed 2023-10-17.

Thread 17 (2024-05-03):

Using the voltage reader function for higher voltages?

anglerfish27, 2024-05-03:
Is it possible to use the code for checking the amount of voltage of the battery to a much higher voltage if you make the appropriate changes in the helper file? Say I wanted to see what the voltage of a 48V battery is, would that work? Would other parts of the code need modification besides the part that sets it to 4.2v currently?

Cheers.

UnexpectedMaker, 2024-05-03:
Absolutely not! You’ll blow up the IO on the ESP32 chip. The voltage divider on the board is there to reduce the voltage going to the IO to make a 4.2V max voltage fit into the ADC range.

Closed 2024-05-13.

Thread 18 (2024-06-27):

Platformio: S3 UM boards.json does not use tinyuf2

Jason2866, 2024-06-27:
@UnexpectedMaker The S3 boards.json currently used in Platformio are not using the tinyuf2 scheme (like in ArduinoIDE).
Example: https://github.com/platformio/platform-espressif32/blob/develop/boards/um_tinys3.json
Is this intended?

It is easy possible to do as done here for an Adafruit board: https://github.com/platformio/platform-espressif32/blob/develop/boards/adafruit_feather_esp32s3_reversetft.json

UnexpectedMaker, 2024-06-27:
Most of my S3 boards were not added by me, but by other people, likely before I added uf2 support.

I'll add it to my list of things to get to, thanks :)

Closed 2025-08-24.

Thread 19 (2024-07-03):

(feature request) - new product - PicoS3; an inside-your-usb-a-port-sized full-featured MCU !

gitcnd, 2024-07-03:
I'm dreaming of the PicoS3 (new invention).

It's half the size of your NanoS3, with USB-A pads on the bottom, and low-profile enough to plug directly in to a USB socket, leaving nothing more than the width of the antenna poking out, beside which is a 4-pin JST SH socket (which can be used for  I²C when plugged in to a host USB device, or which can be used to power the device if it's not connected inside a USB-A socket.

It's so tiny, customers could even "hack it inside" to the plug of an existing cable, without even knowing it's inside there.

It would "expose" as many as possible other useful pins as teeny-tiny solderable points on the underside, which are covered-over with a solder mask (if we want to use them, we need to scrape off the mask first), and the very edge of the connector (below the antenna) exposes enough non-masked contact area pads that sensing a finger-touch on those exposed pins can be managed).

If there's room to cram the WS2812B behind the antenna so we can at least see its glow from inside there, that would be the icing on the minicake !

Closed 2025-08-24.

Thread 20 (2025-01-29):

OMGS3 Power Path missing USB connection?

tylercrumpton, 2025-01-29:
Hiya! First off, thanks so much for sharing these schematics and symbols and part symbols, I've learned a lot for my own personal projects ever since buying some of your FeatherS2's!

Looking at the Power Path on the [schematic for the OMGS3](https://github.com/UnexpectedMaker/esp32s3/blob/main/schematics/schematic-omgs3.pdf), it seems like there is supposed to be an USB power connection to the net attached to the gate of the battery isolation PMOS (T3)? Without it, I don't see how the gate would ever be closed if battery voltage is present.

UnexpectedMaker, 2025-01-29:
There is a USB connection there - looks like I had the label hidden, sorry. I'll fix that and update the schematic when I get a chance.

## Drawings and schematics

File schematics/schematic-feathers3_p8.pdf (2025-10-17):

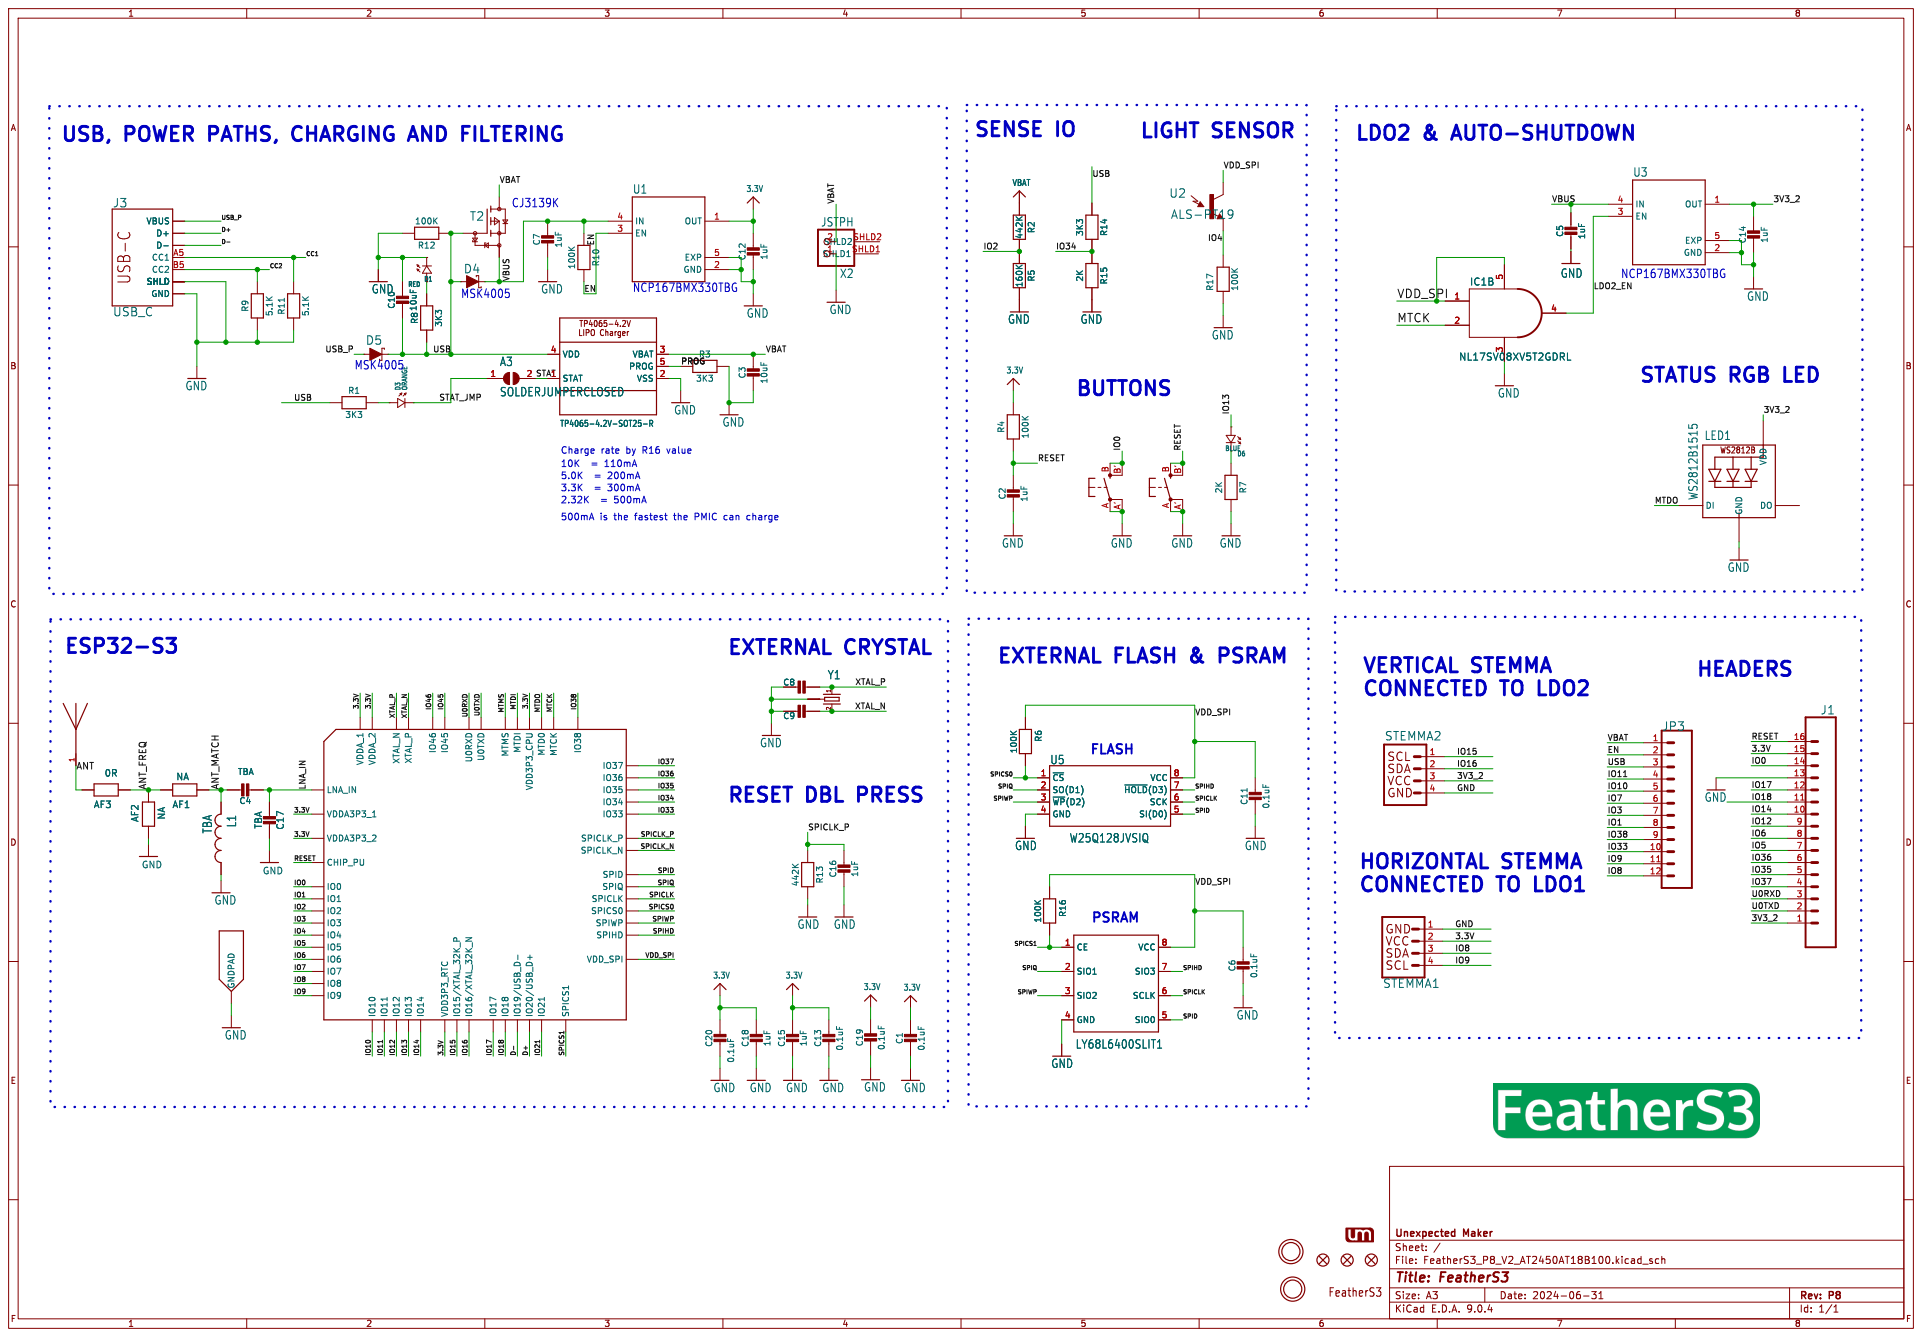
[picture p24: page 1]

500mA is the fastest the PMIC can charge

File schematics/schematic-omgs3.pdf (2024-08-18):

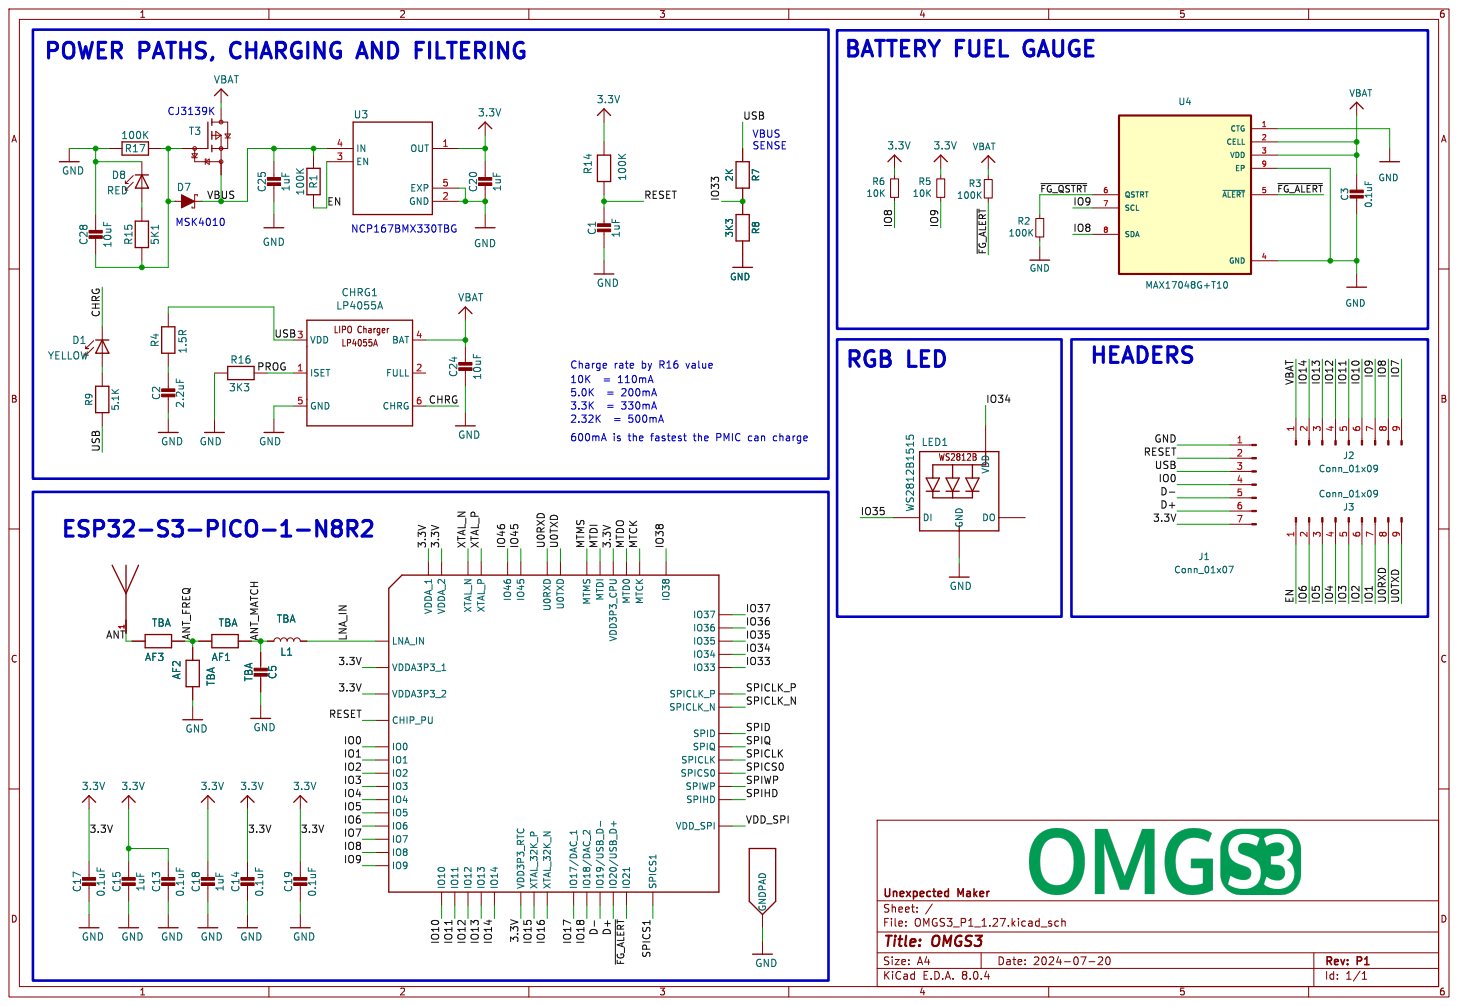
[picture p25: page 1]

POWER PATHS, CHARGING AND FILTERING

600mA is the fastest the PMIC can charge

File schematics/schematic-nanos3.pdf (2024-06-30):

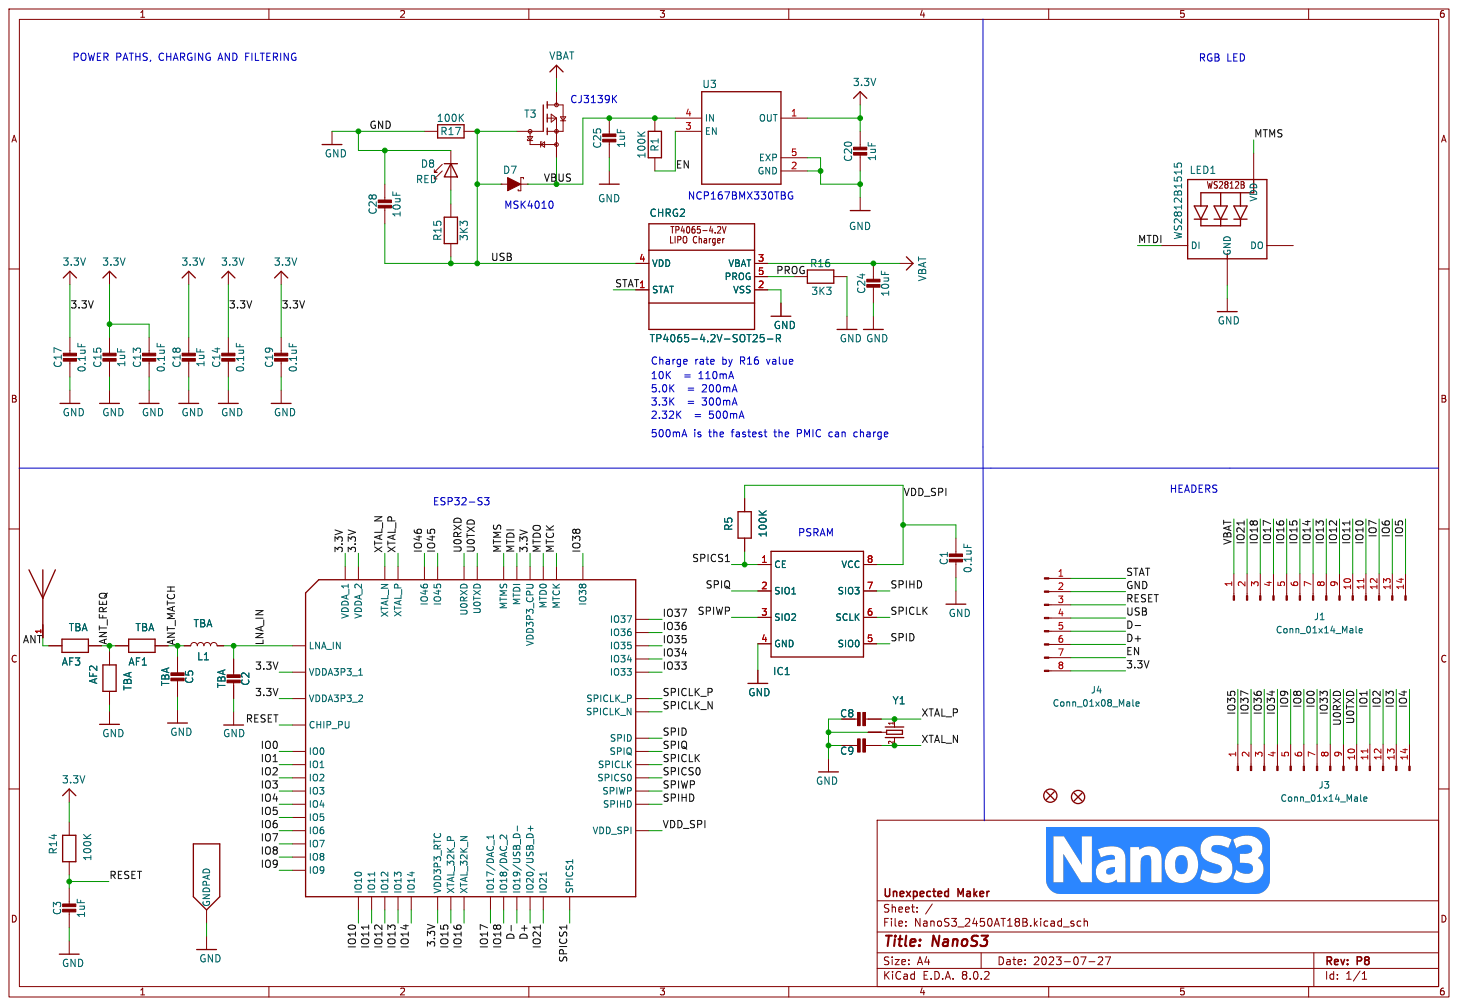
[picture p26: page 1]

POWER PATHS, CHARGING AND FILTERING

500mA is the fastest the PMIC can charge PSRAM

1 2 Y1 CE 1 SIO1 2 SIO2 3 GND 4 SIO0 5 SCLK 6 SIO3 7 VCC 8

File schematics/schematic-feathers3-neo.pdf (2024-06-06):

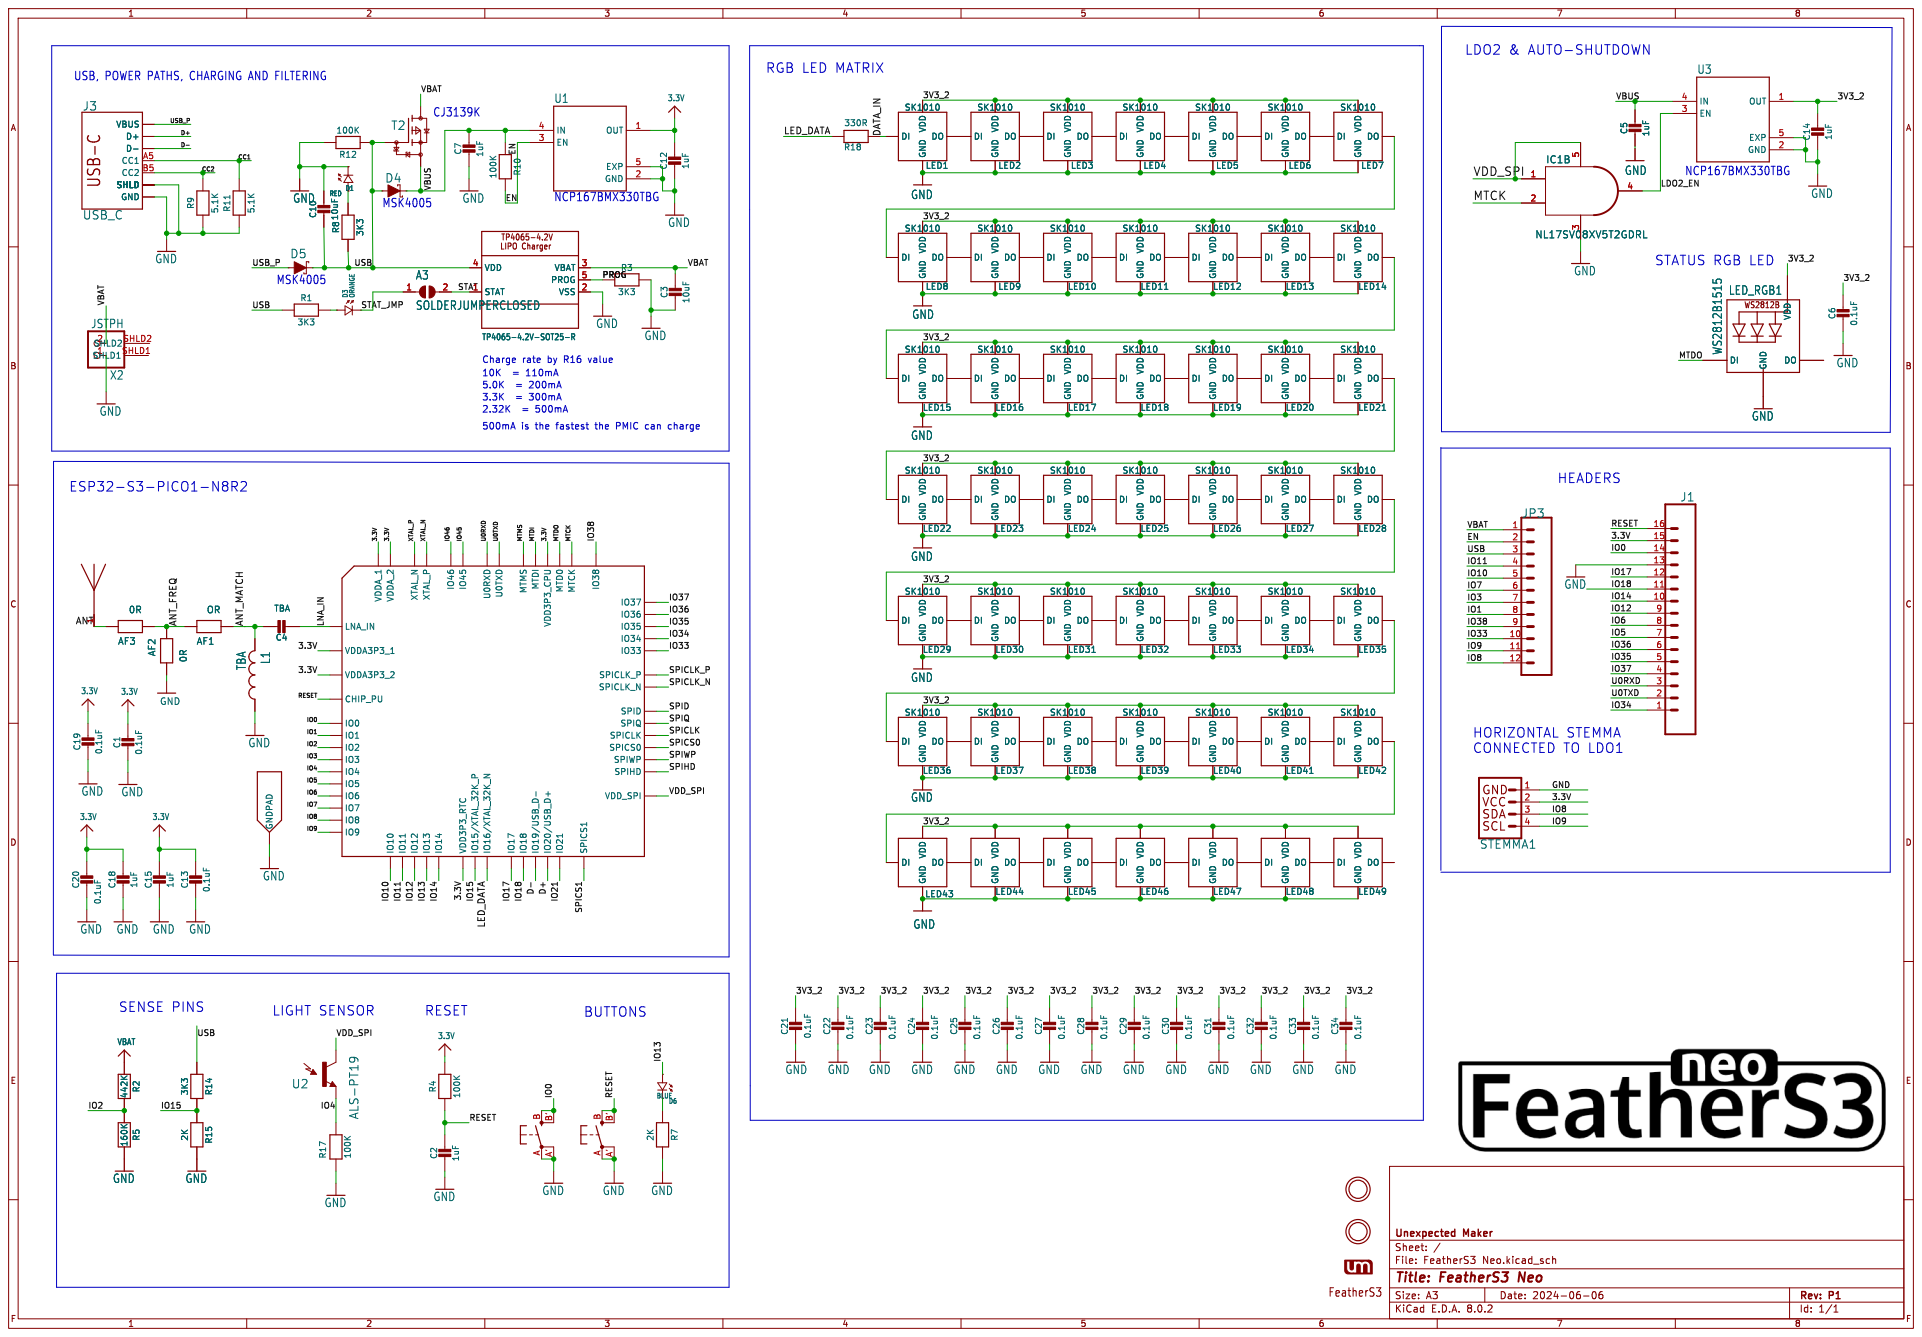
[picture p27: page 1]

USB, POWER PATHS, CHARGING AND FILTERING

5 LED21 SK1010 DI DO GND VDD LED7 SK1010 DI DO GND VDD

500mA is the fastest the PMIC can charge

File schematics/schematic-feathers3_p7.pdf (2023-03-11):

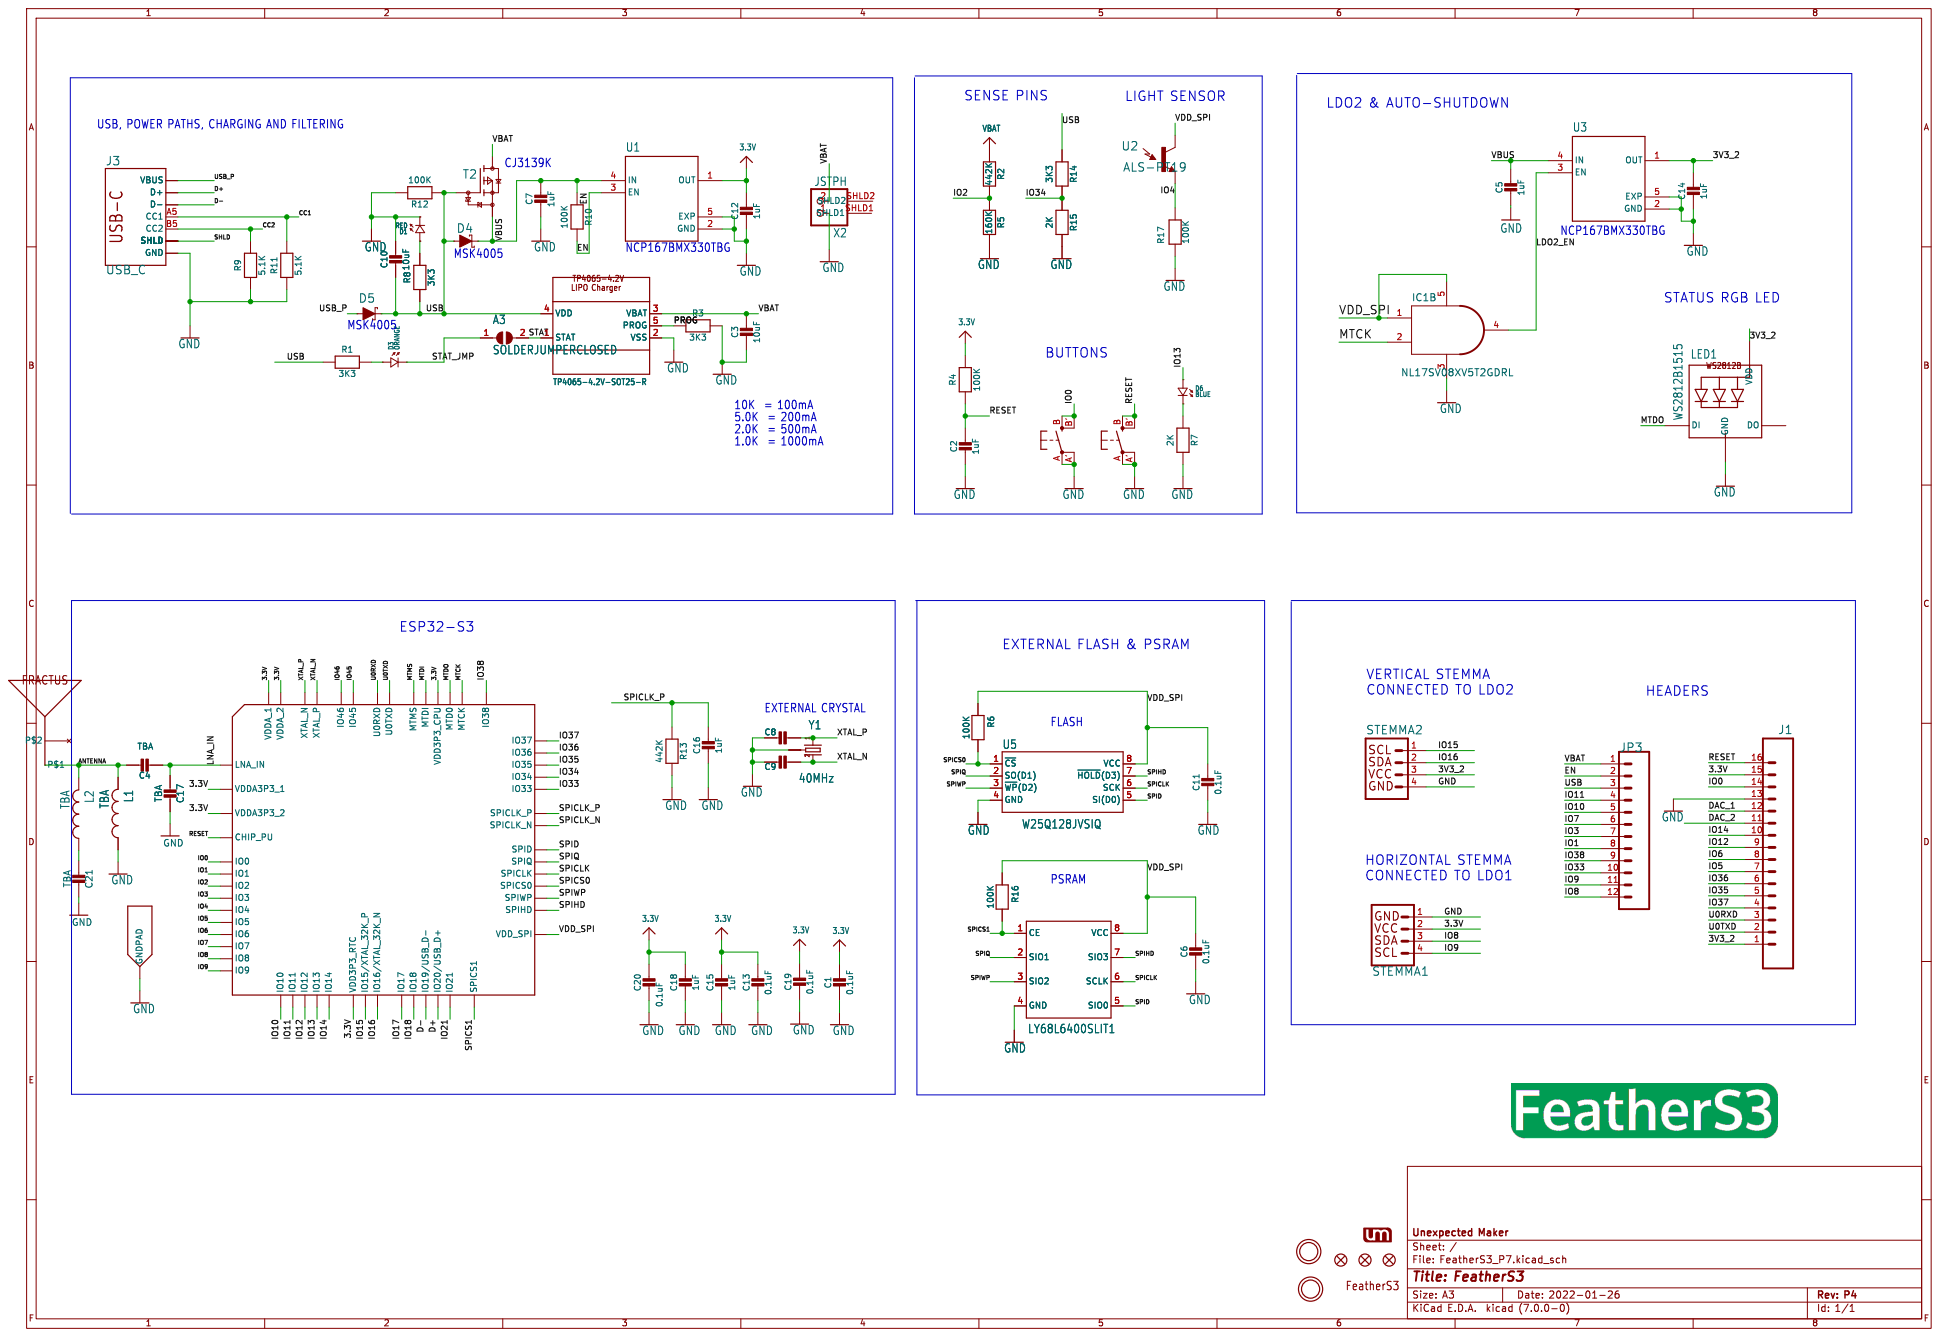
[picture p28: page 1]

VERTICAL STEMMA CONNECTED TO LDO2 PSRAM

File: FeatherS3_P7.kicad_sch Sheet: / Unexpected Maker

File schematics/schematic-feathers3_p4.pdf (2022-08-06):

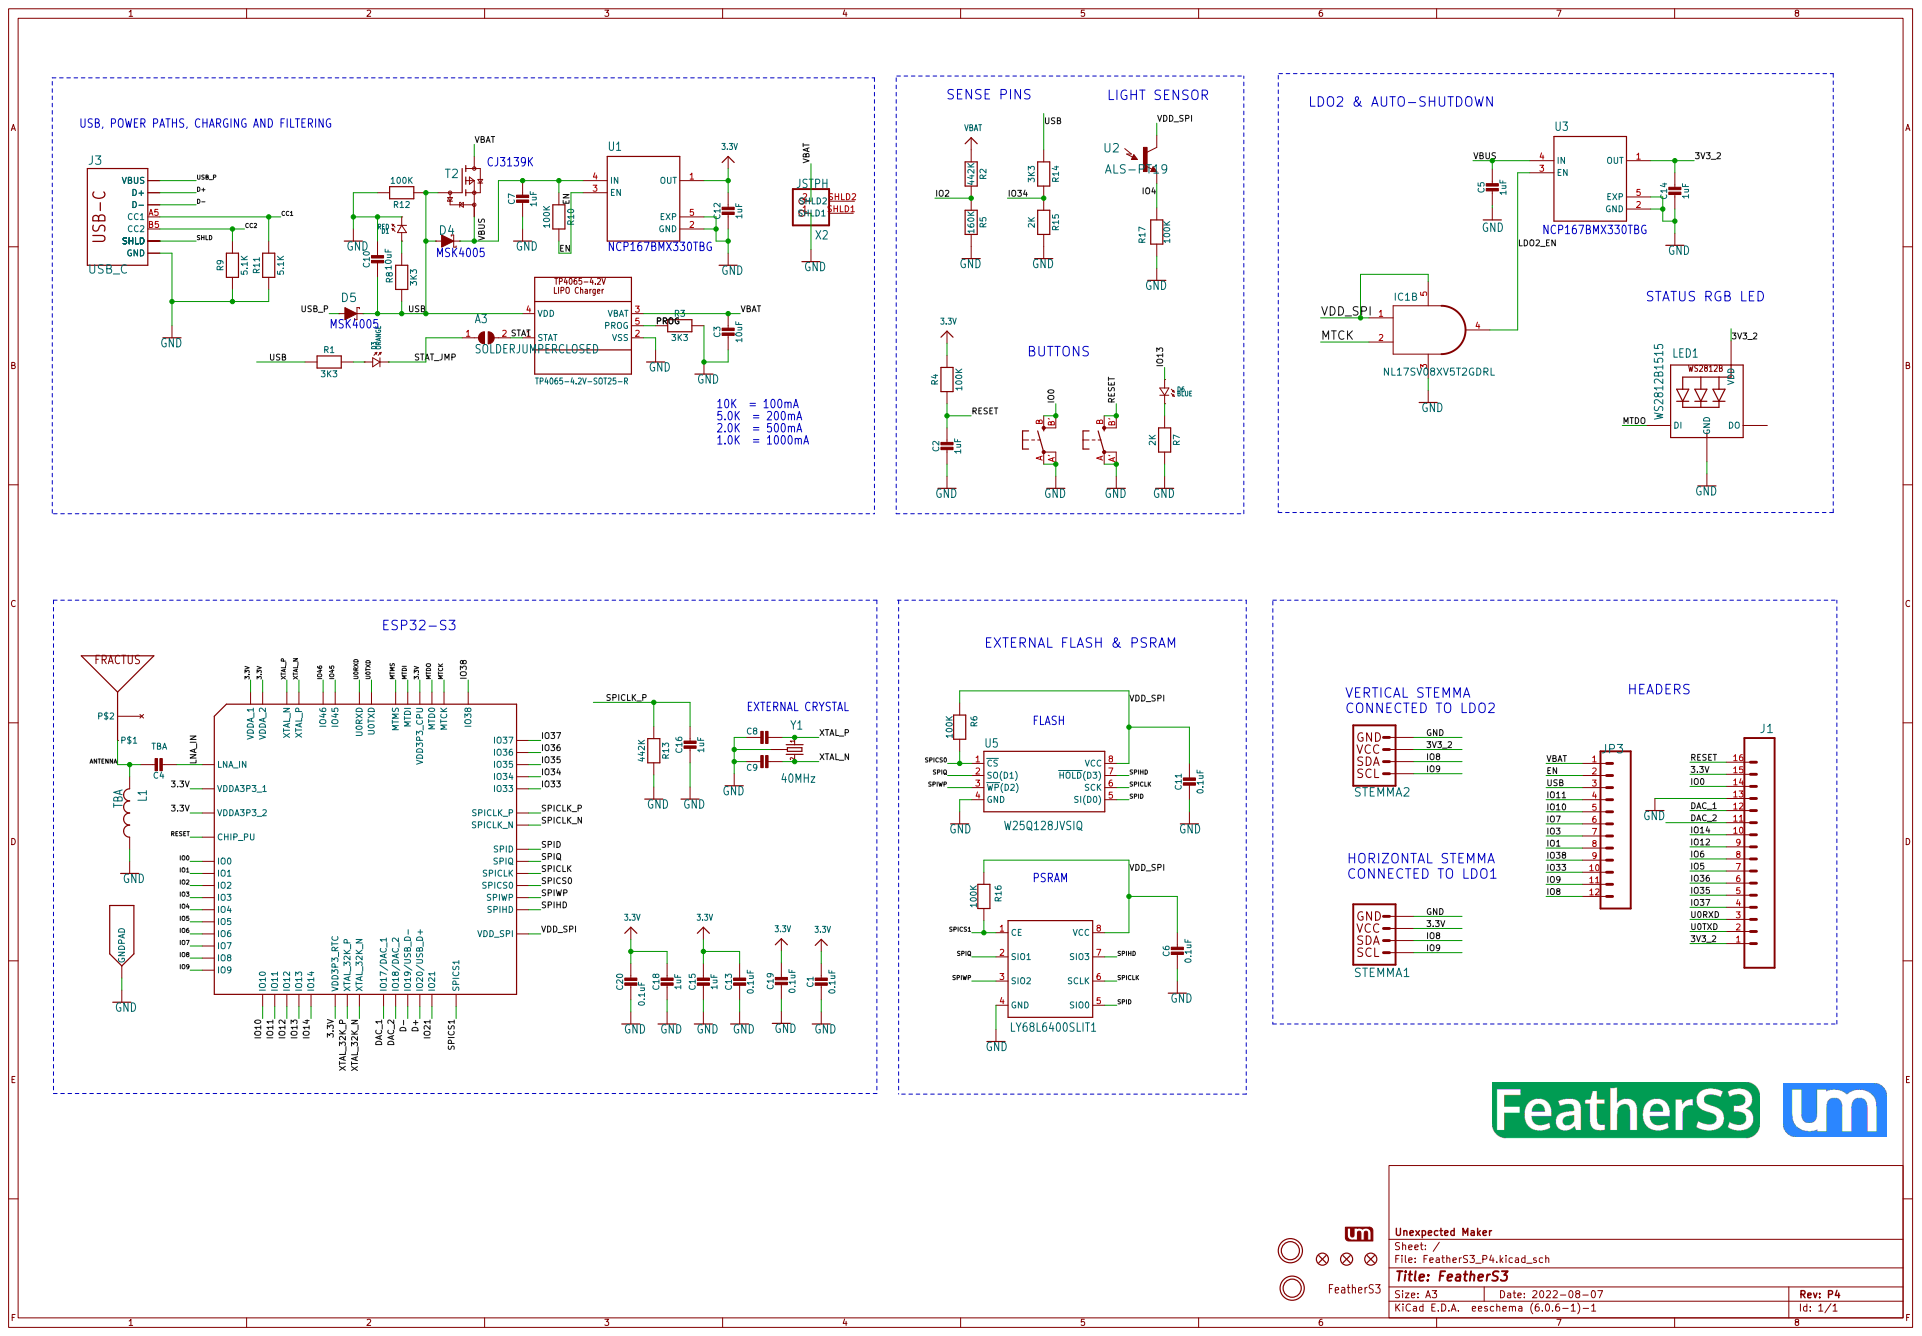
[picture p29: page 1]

USB, POWER PATHS, CHARGING AND FILTERING

File: FeatherS3_P4.kicad_sch Sheet: / Unexpected Maker

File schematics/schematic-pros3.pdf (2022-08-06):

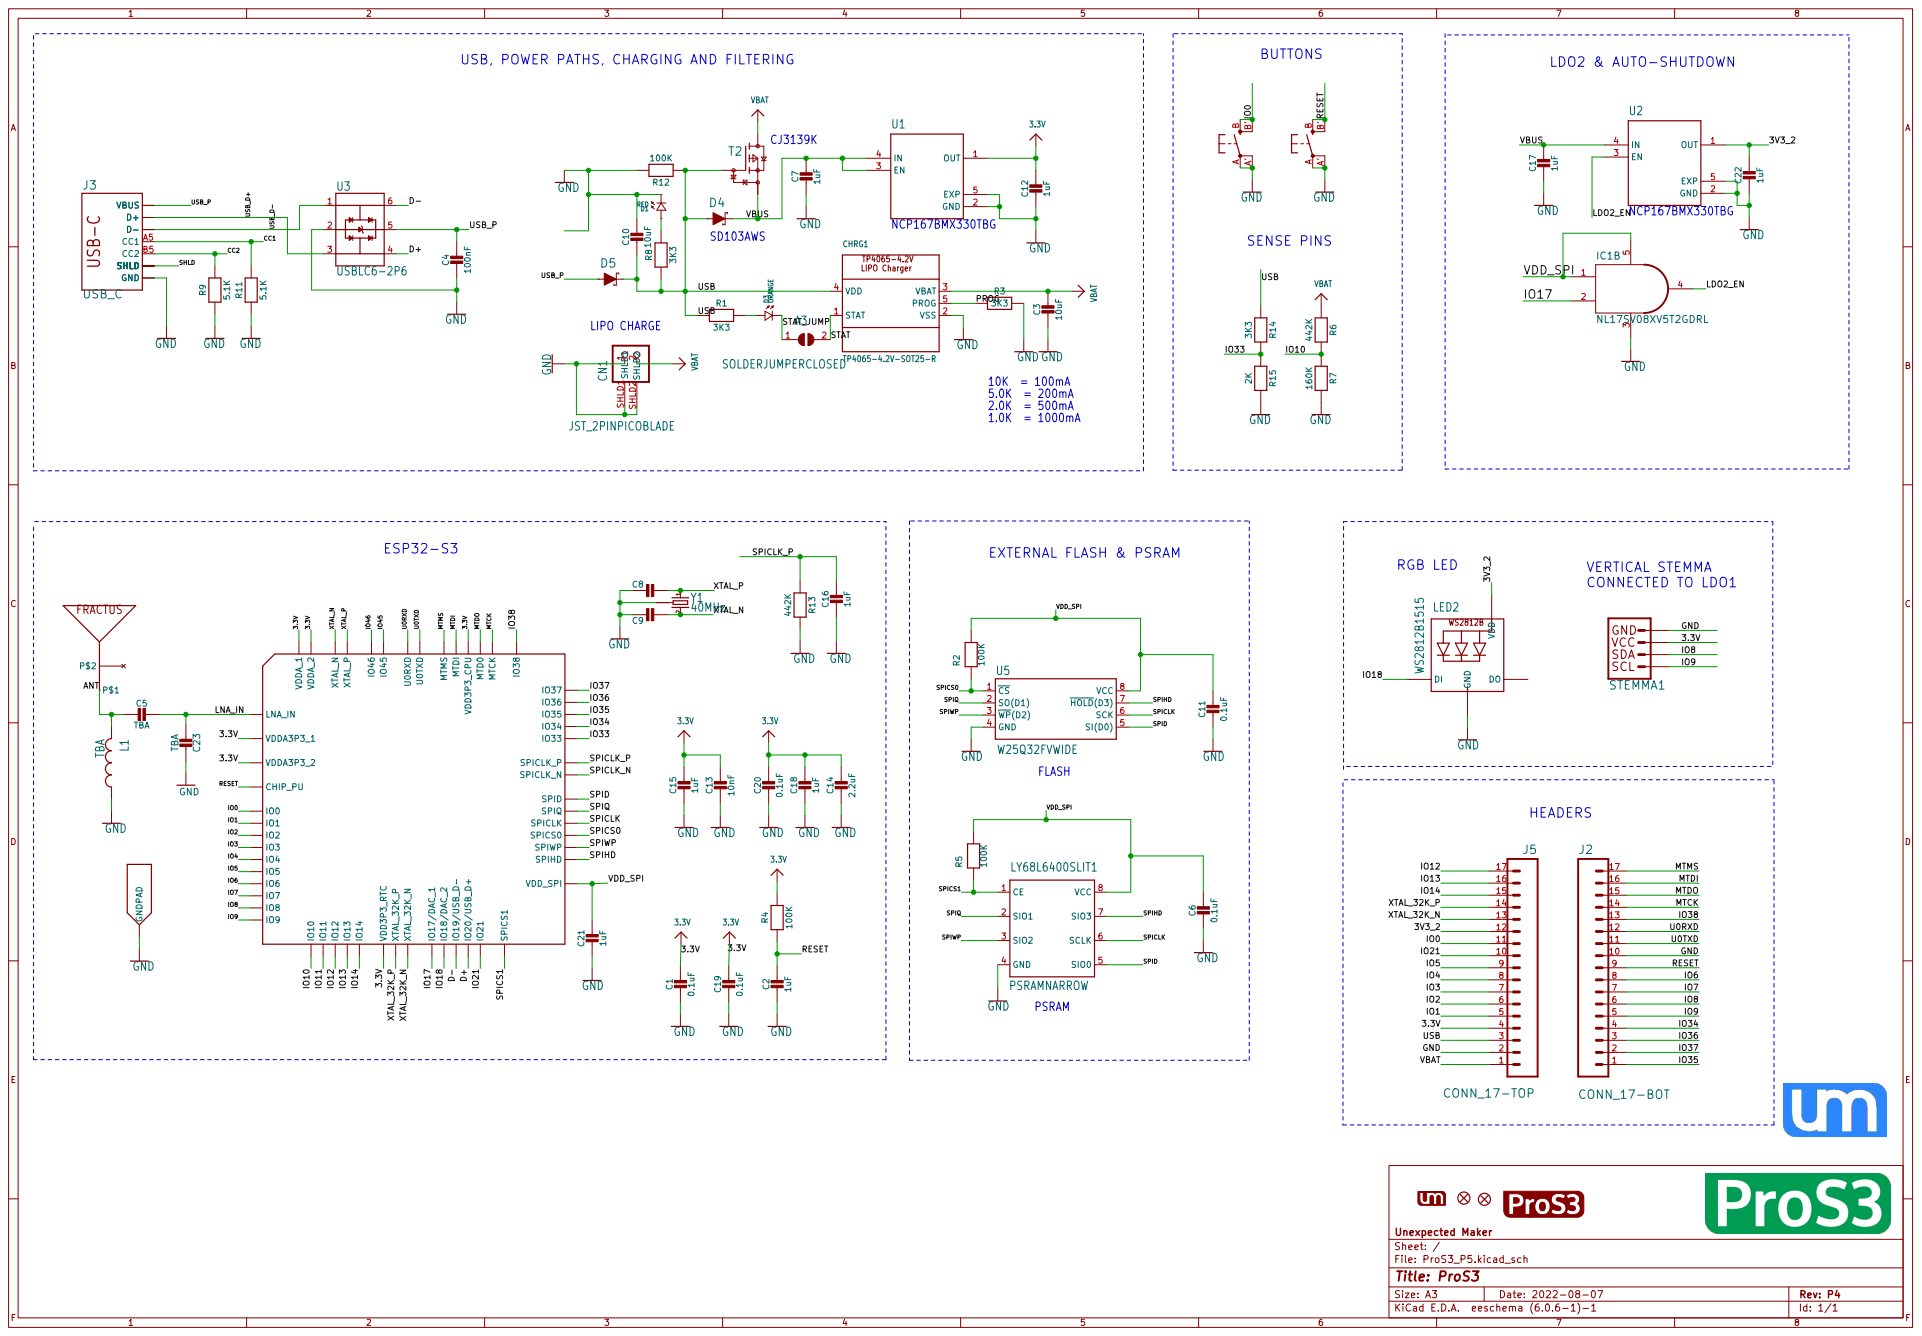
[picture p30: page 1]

BUTTONS USB, POWER PATHS, CHARGING AND FILTERING

AA' BB' OUT 1 GND 2 EN 3

File: ProS3_P5.kicad_sch Sheet: / Unexpected Maker

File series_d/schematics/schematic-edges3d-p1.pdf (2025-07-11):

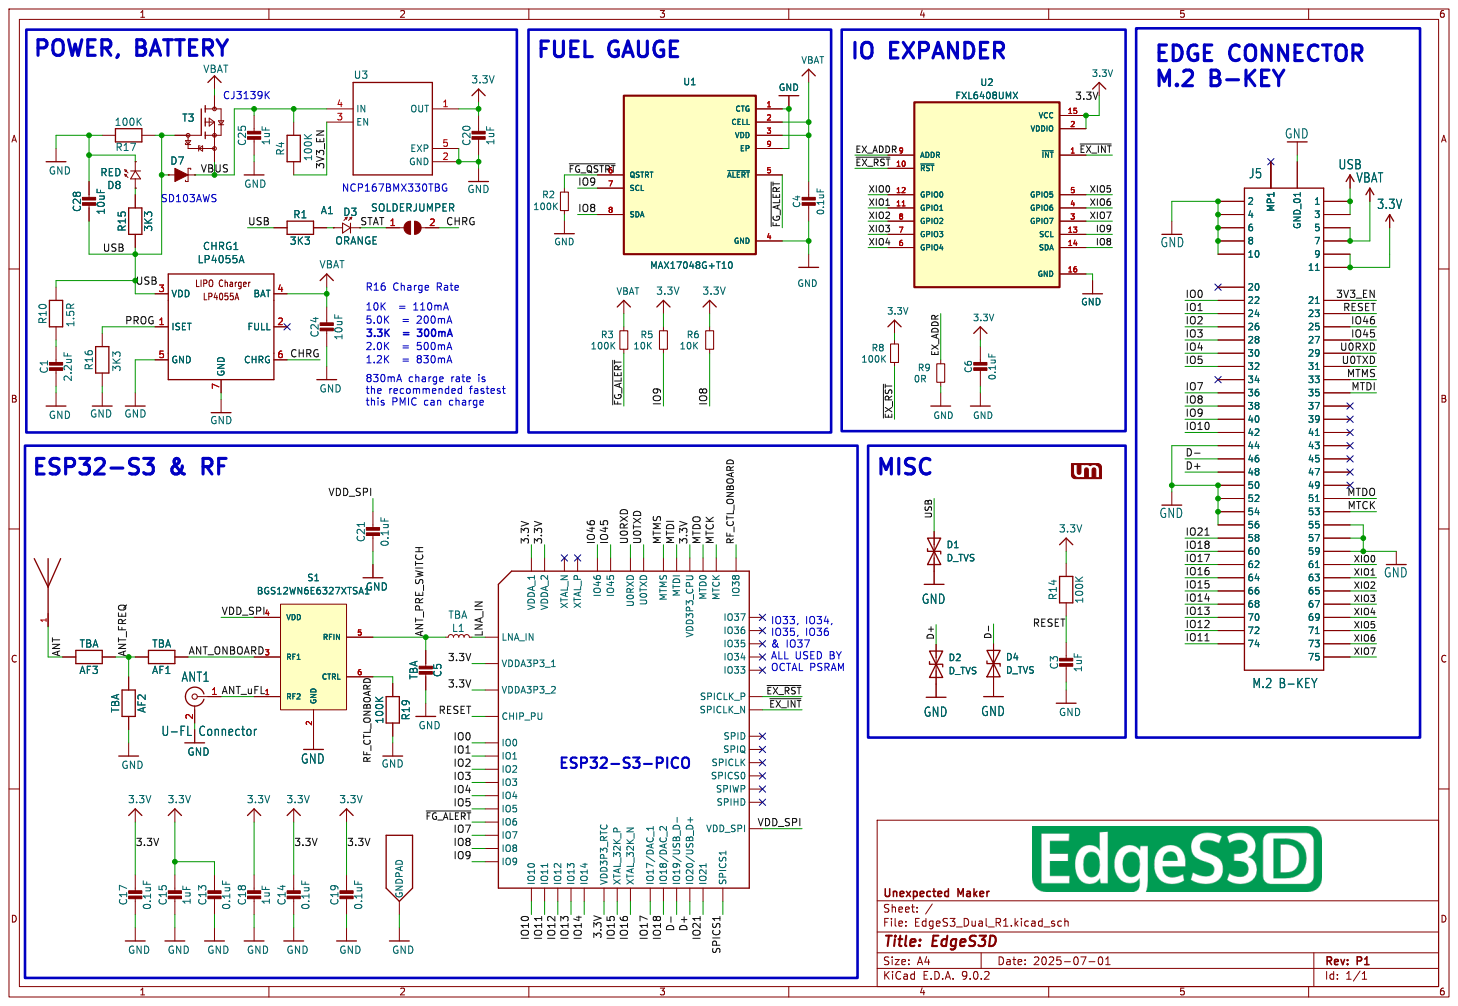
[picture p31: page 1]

7 BAT 4 FULL 2 CHRG 6 R15 3K3 C28 10uF D8 RED

this PMIC can charge R16 Charge Rate

1 AF3 TBA GND C15 1uF GND GND GND TBA AF2 C21 0.1uF GND

2 AF3 TBA TBA AF2 GND TBA C5 R19 100K

IO35, IO36 & IO37 ALL USED BY OCTAL PSRAM

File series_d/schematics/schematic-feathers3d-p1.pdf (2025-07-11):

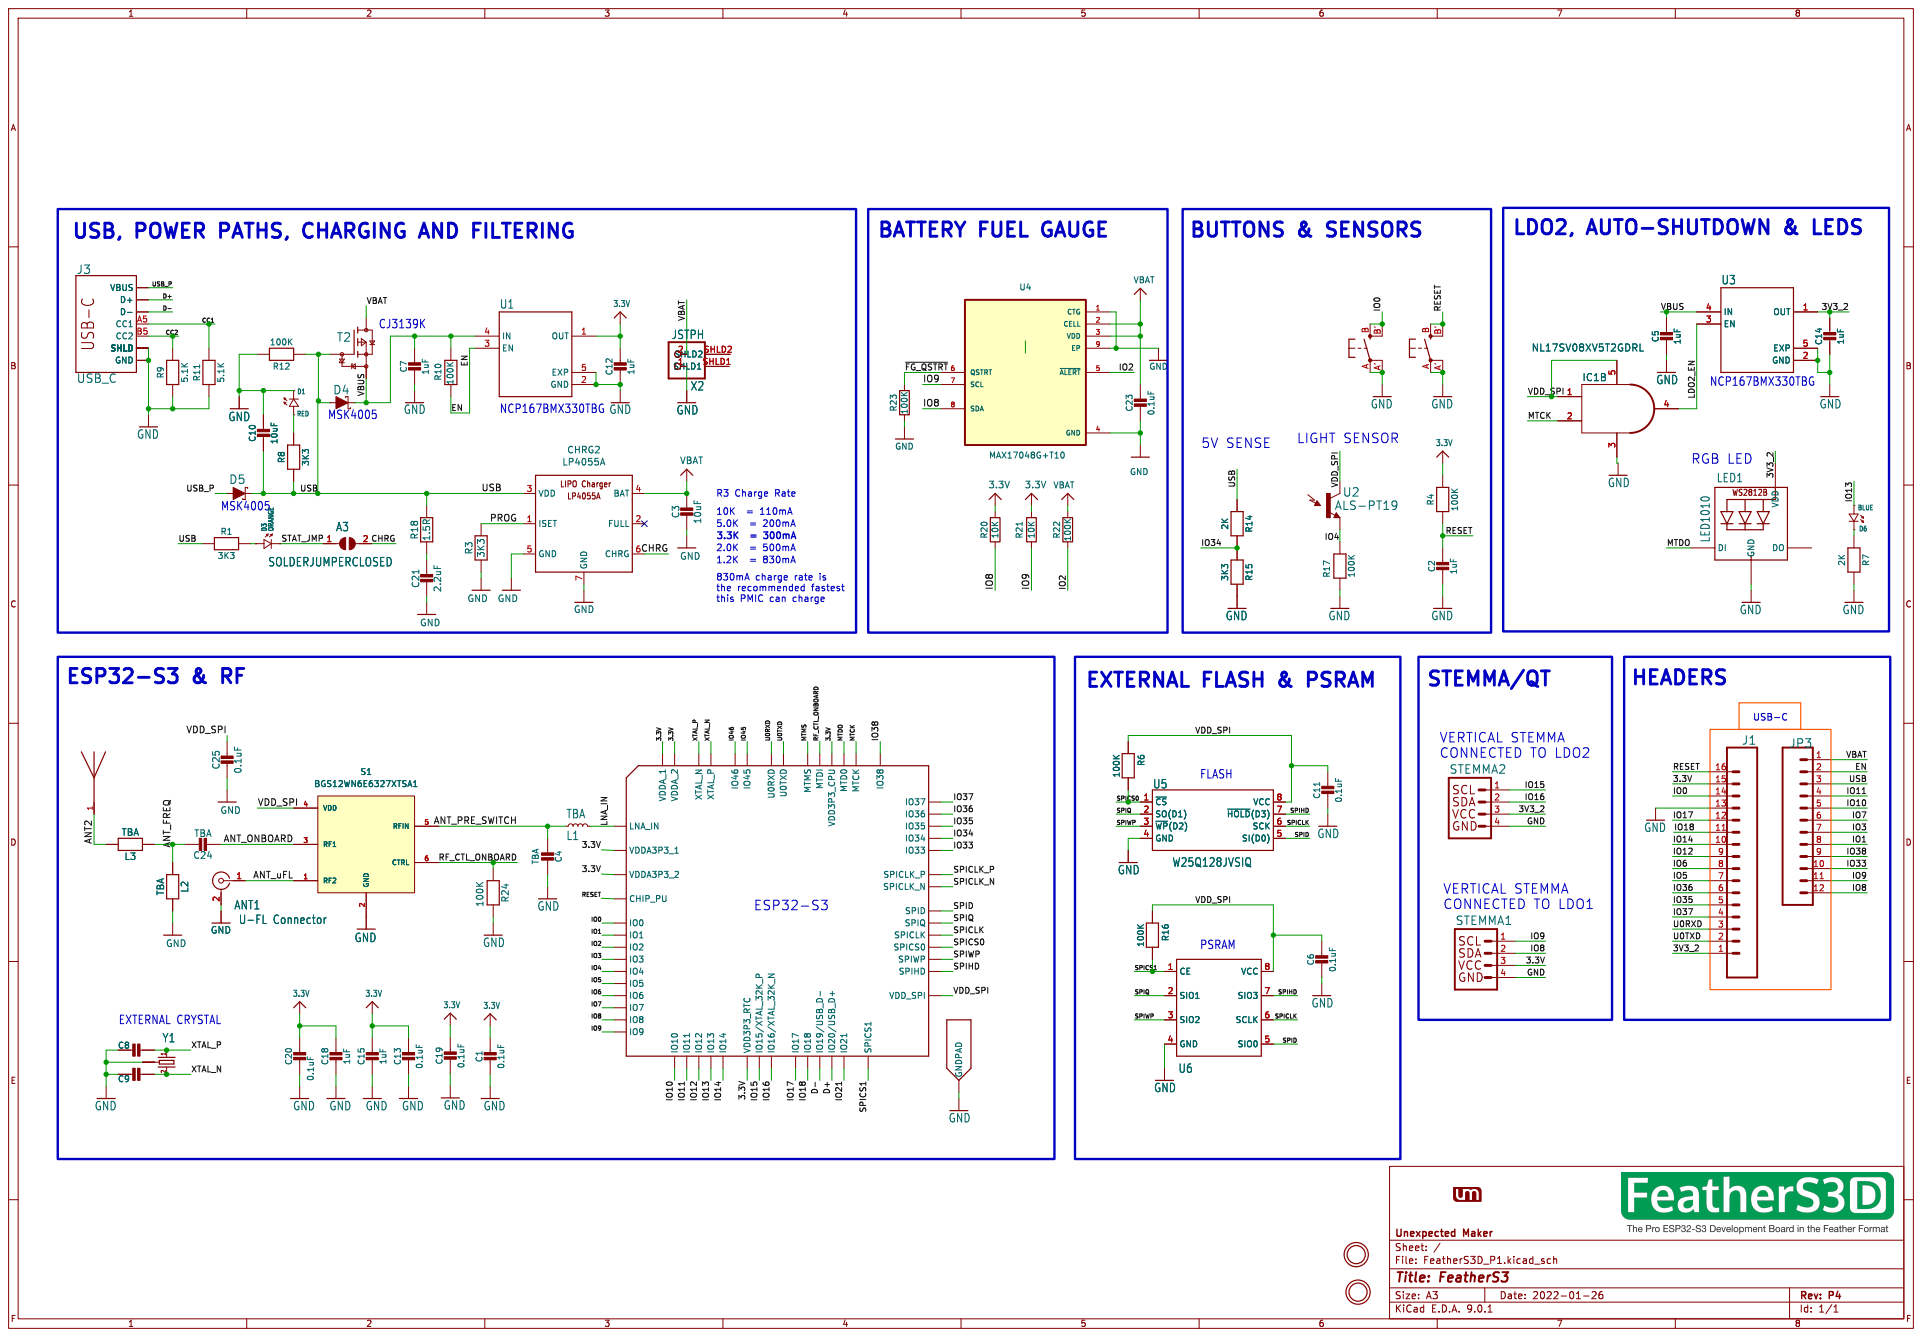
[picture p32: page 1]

USB, POWER PATHS, CHARGING AND FILTERING
VBUS D+D- CC1 A5 CC2 B5 SHLD GND

830mA charge rate is
this PMIC can charge

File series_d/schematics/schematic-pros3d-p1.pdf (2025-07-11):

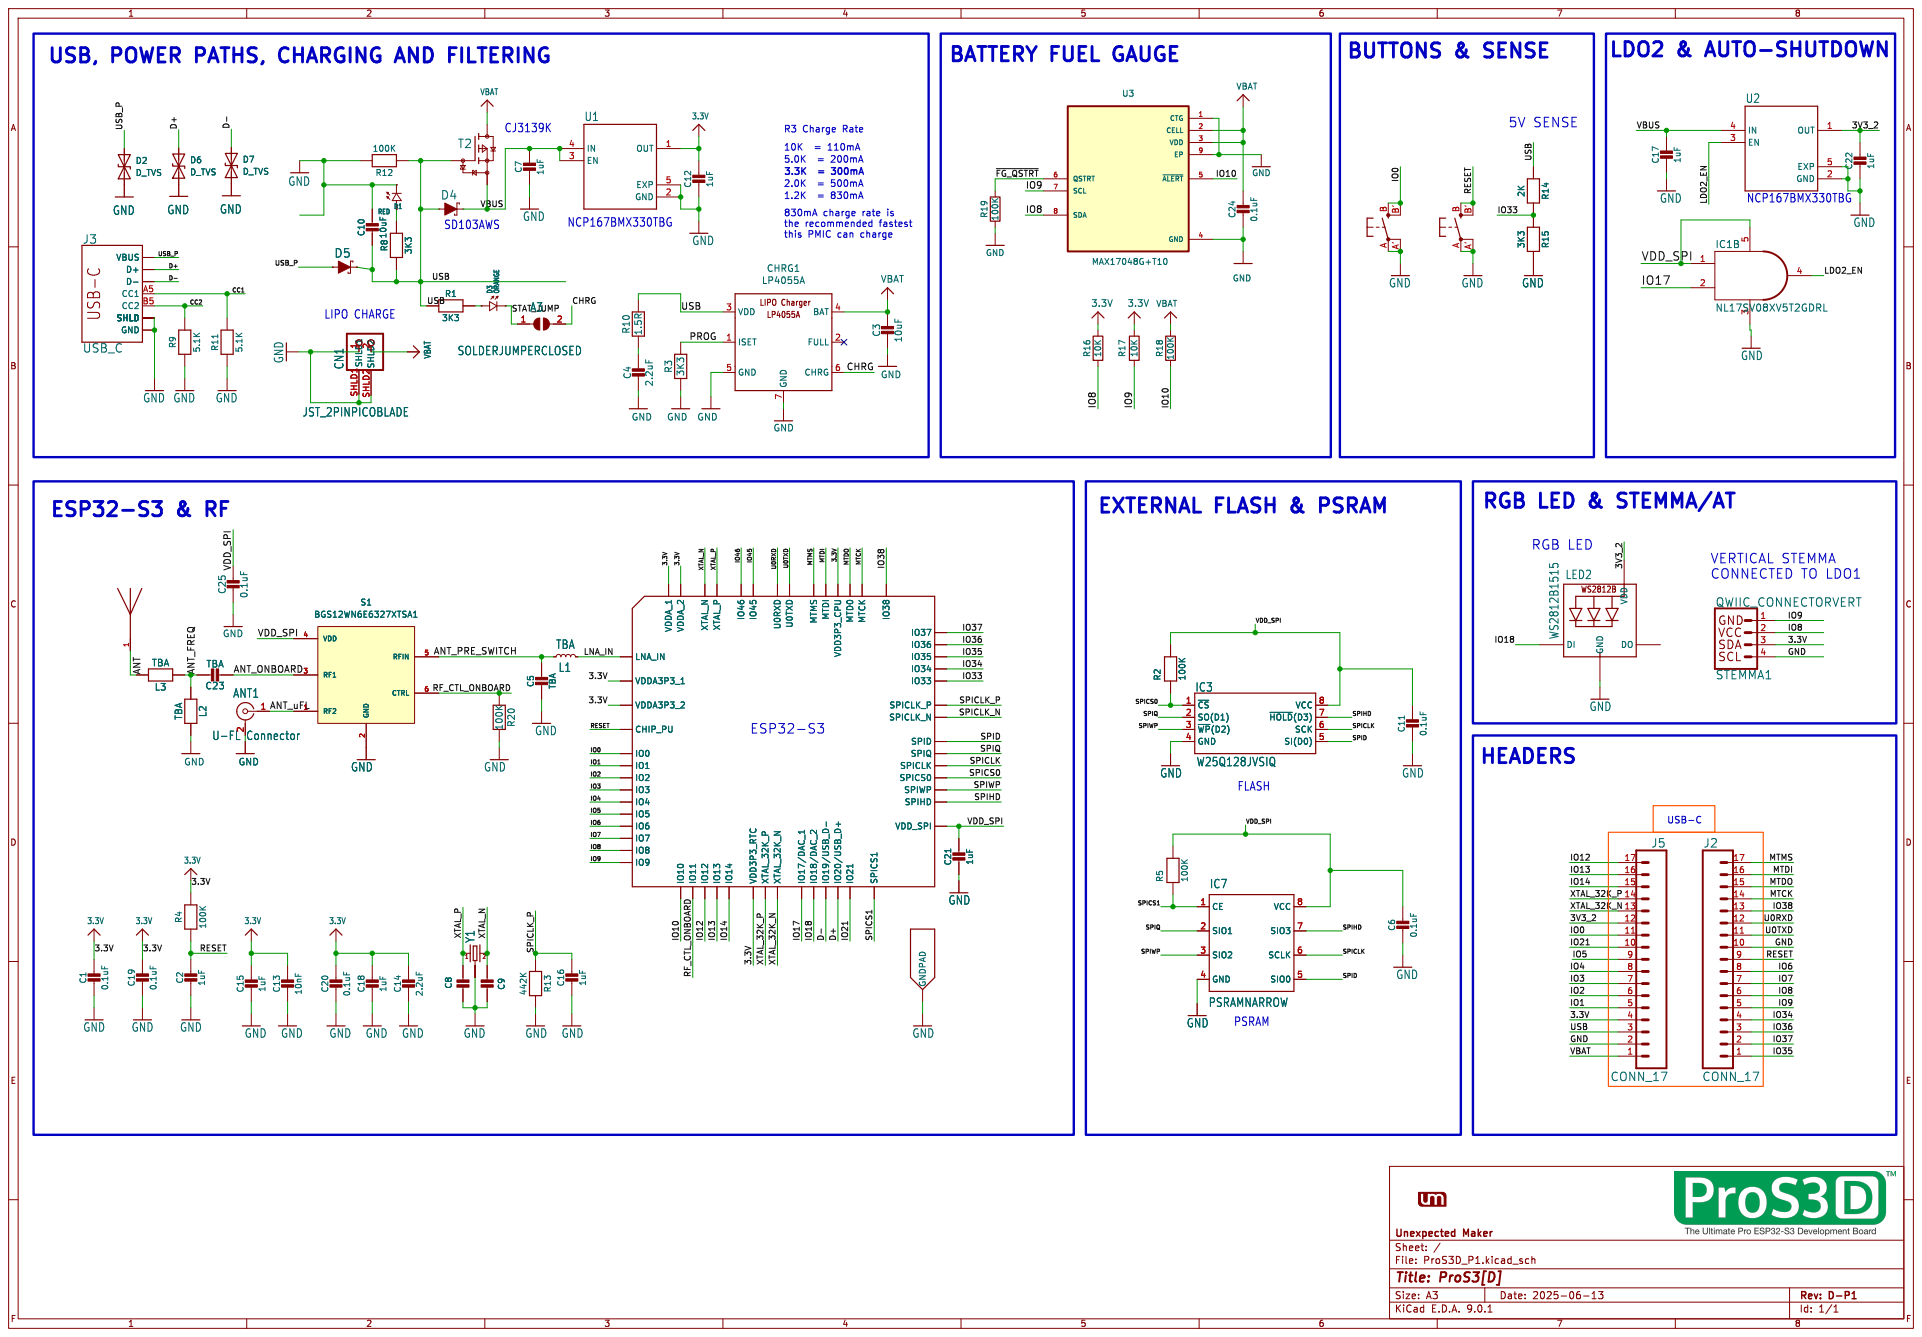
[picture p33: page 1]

USB, POWER PATHS, CHARGING AND FILTERING

830mA charge rate is
this PMIC can charge

RGB LED & STEMMA/AT

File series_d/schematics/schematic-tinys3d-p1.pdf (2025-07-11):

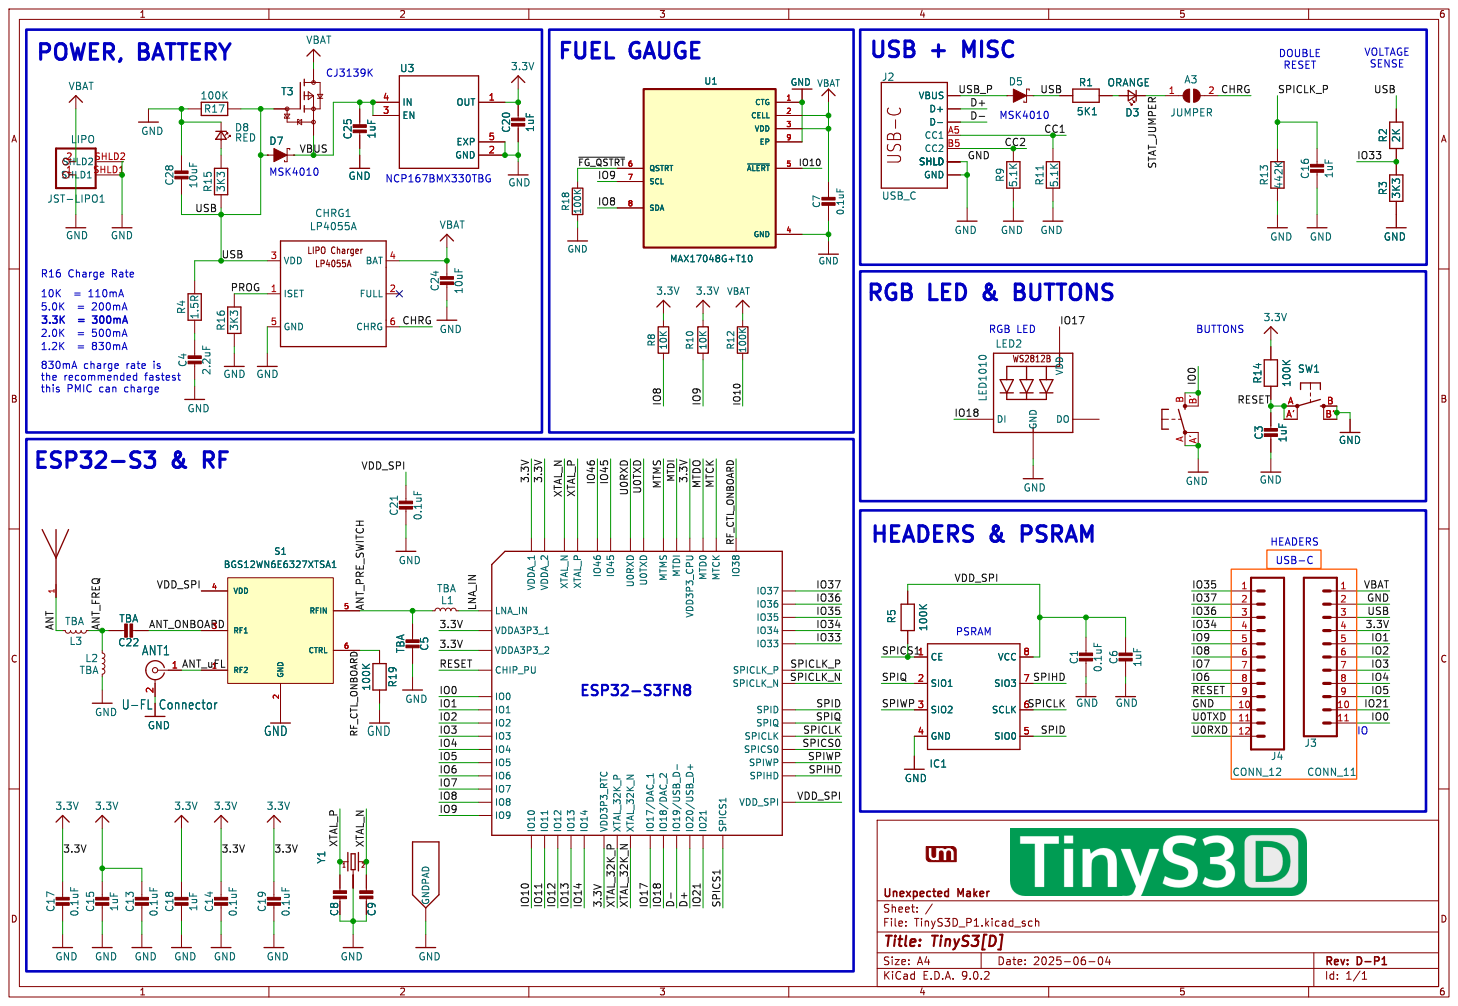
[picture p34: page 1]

830mA charge rate is
this PMIC can charge

AA' BB' WS2812B DI GND VDD

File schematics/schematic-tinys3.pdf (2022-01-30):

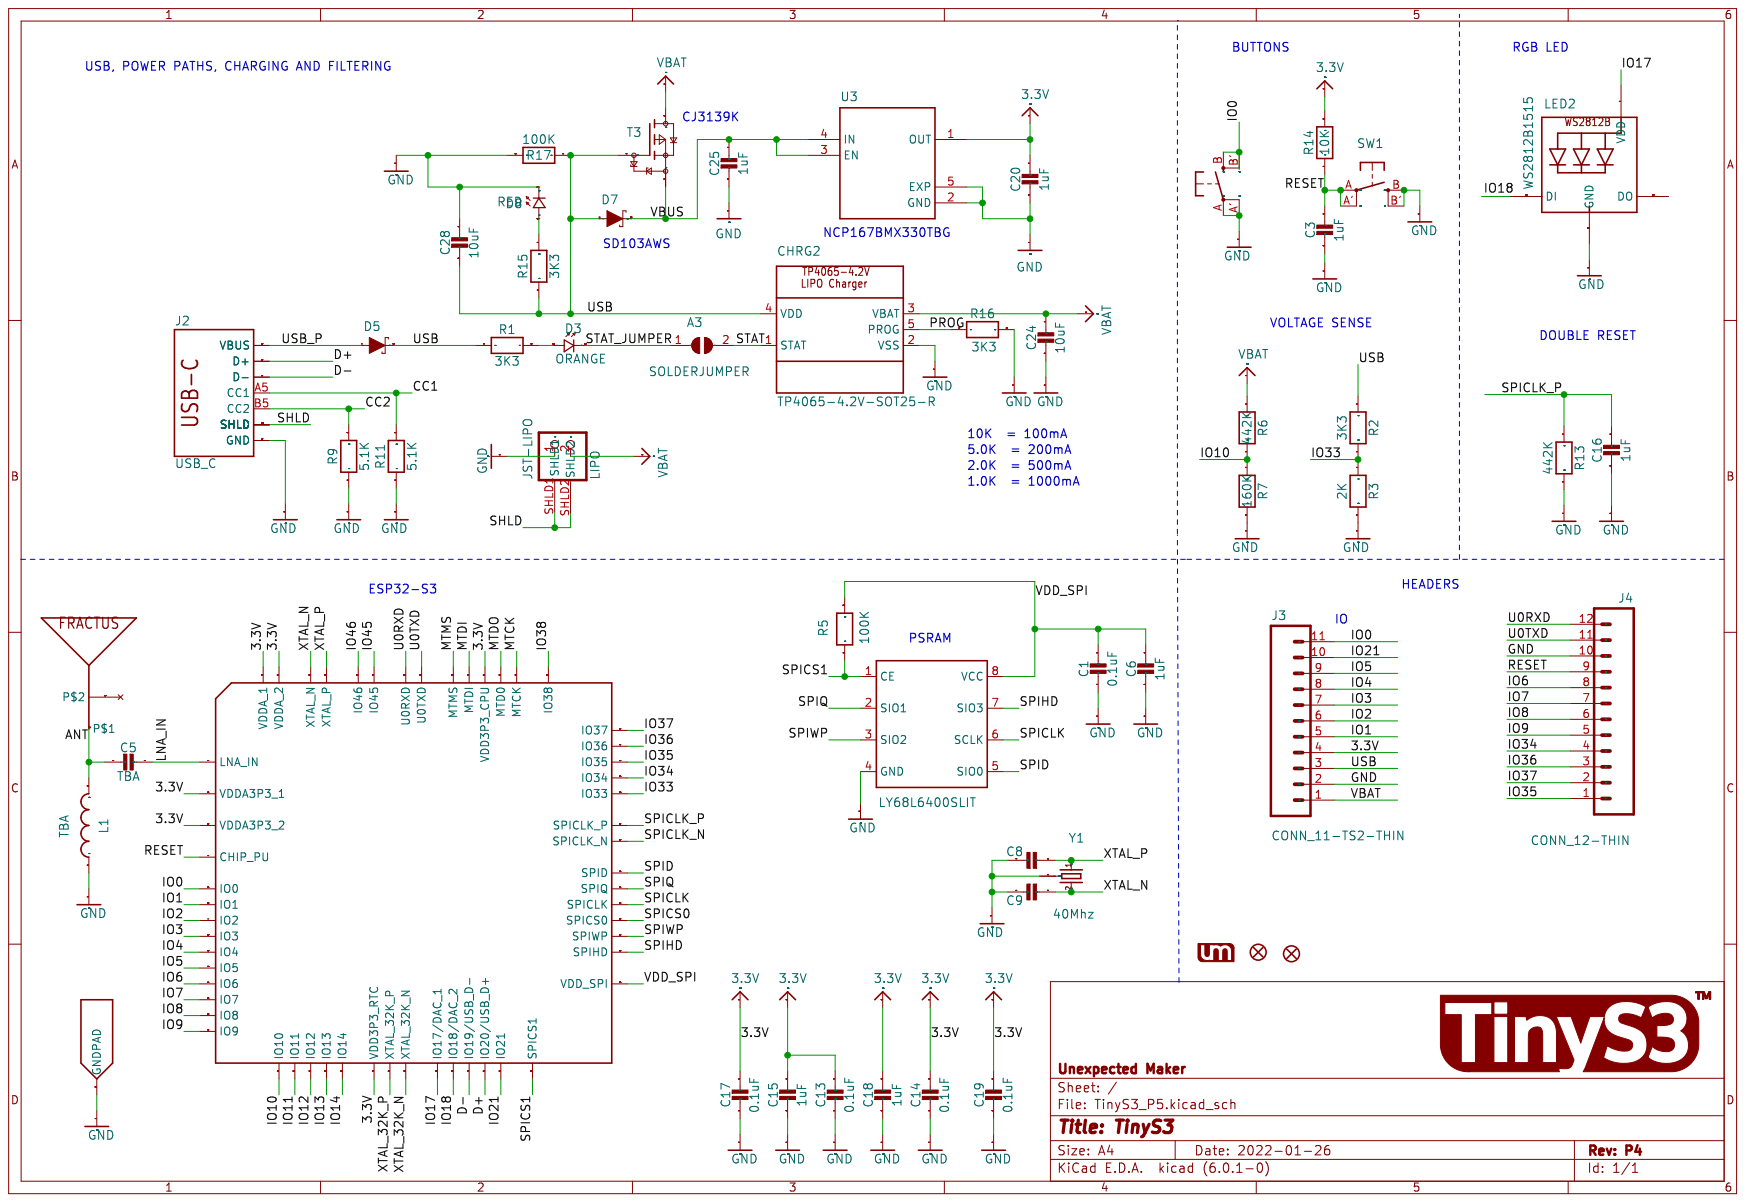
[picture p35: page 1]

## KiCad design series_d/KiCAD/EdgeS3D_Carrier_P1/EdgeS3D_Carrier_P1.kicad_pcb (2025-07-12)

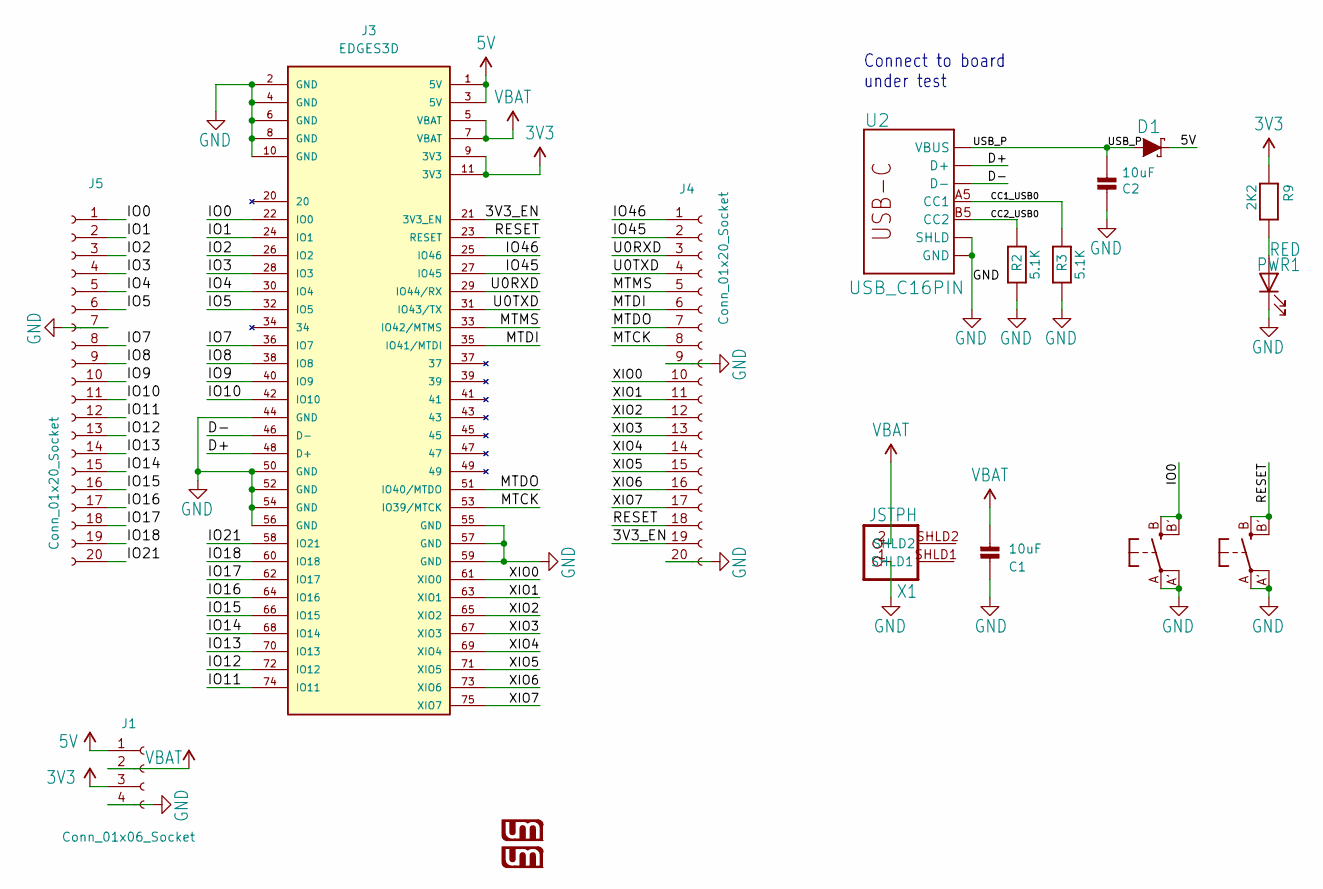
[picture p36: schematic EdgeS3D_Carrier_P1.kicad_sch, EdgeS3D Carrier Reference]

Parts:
C1, C2: 10uF; C_0603_1608Metric
D1: DIODE-SCHOTTKYWIDE; SOD-523-MSK4010
J1: Conn_01x06_Socket; PinHeader_1x04_P2.54mm_Vertical
J3: EDGES3D; AMPHENOL_MDT275B03001; PARTREV 7
J4, J5: Conn_01x20_Socket; PinHeader_1x20_P2.54mm_Vertical
PWR1: RED; LED_0805_2012Metric
R2, R3: 5.1K; R_0402_1005Metric
R9: 2K2; _0805MP
SW1, SW2: KMR2; BTN_KMR2_4.6X2.8
U2: USB_C16PIN; USB-C-16P-LESSPASTE-2-FIxed
U$1, U$2: UM_LOGONEW_SMALL; UM_LOGO_NEW_SMALL
X1: JSTPH; JST-PICOBLADE

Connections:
3V3: J1.3, J3.9 (3V3), J3.11 (3V3), R9.1
5V: D1.C, J1.1, J3.1 (5V), J3.3 (5V)
/3V3_EN: J3.21 (3V3_EN), J4.19
/CC1_USB0: R3.2, U2.A5 (CC1)
/CC2_USB0: R2.2, U2.B5 (CC2)
/D+: J3.48 (D+), U2.A6 (D+), U2.B6 (D+)
/D-: J3.46 (D-), U2.A7 (D-), U2.B7 (D-)
/IO0: J3.22 (IO0), J5.1, SW1.B (S), SW1.B' (S1)
/IO1: J3.24 (IO1), J5.2
/IO2: J3.26 (IO2), J5.3
/IO3: J3.28 (IO3), J5.4
/IO4: J3.30 (IO4), J5.5
/IO5: J3.32 (IO5), J5.6
/IO7: J3.36 (IO7), J5.8
/IO8: J3.38 (IO8), J5.9
/IO9: J3.40 (IO9), J5.10
/IO10: J3.42 (IO10), J5.11
/IO11: J3.74 (IO11), J5.12
/IO12: J3.72 (IO12), J5.13
/IO13: J3.70 (IO13), J5.14
/IO14: J3.68 (IO14), J5.15
/IO15: J3.66 (IO15), J5.16
/IO16: J3.64 (IO16), J5.17
/IO17: J3.62 (IO17), J5.18
/IO18: J3.60 (IO18), J5.19
/IO21: J3.58 (IO21), J5.20
/IO45: J3.27 (IO45), J4.2
/IO46: J3.25 (IO46), J4.1
/MTCK: J3.53 (IO39/MTCK), J4.8
/MTDI: J3.35 (IO41/MTDI), J4.6
/MTDO: J3.51 (IO40/MTDO), J4.7
/MTMS: J3.33 (IO42/MTMS), J4.5
/RESET: J3.23 (RESET), J4.18, SW2.B (S), SW2.B' (S1)
/U0RXD: J3.29 (IO44/RX), J4.3
/U0TXD: J3.31 (IO43/TX), J4.4
/USB_P: C2.2, D1.A, U2.VBUS1 (VBUS), U2.VBUS2 (VBUS)
/XIO0: J3.61 (XIO0), J4.10
/XIO1: J3.63 (XIO1), J4.11
/XIO2: J3.65 (XIO2), J4.12
/XIO3: J3.67 (XIO3), J4.13
/XIO4: J3.69 (XIO4), J4.14
/XIO5: J3.71 (XIO5), J4.15
/XIO6: J3.73 (XIO6), J4.16
/XIO7: J3.75 (XIO7), J4.17
GND: C1.1, C2.1, J1.4, J3.2 (GND), J3.4 (GND), J3.6 (GND), J3.8 (GND), J3.10 (GND), J3.44 (GND), J3.50 (GND), J3.52 (GND), J3.54 (GND), J3.55 (GND), J3.56 (GND), J3.57 (GND), J3.59 (GND), J4.9, J4.20, J5.7, PWR1.1 (K), R2.1, R3.1, SW1.A, SW1.A' (P1), SW2.A, SW2.A' (P1), U2.GND, U2.GND2 (GND), U2.SHLD, U2.SHLD2 (SHLD), U2.SHLD3 (SHLD), U2.SHLD4 (SHLD), U2.SHLD5 (SHLD), U2.SHLD6 (SHLD), U2.SHLD7 (SHLD), U2.SHLD8 (SHLD), X1.1
unnamed: PWR1.2 (A), R9.2
VBAT: C1.2, J1.2, J3.5 (VBAT), J3.7 (VBAT), X1.2

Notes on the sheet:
Connect to board under test

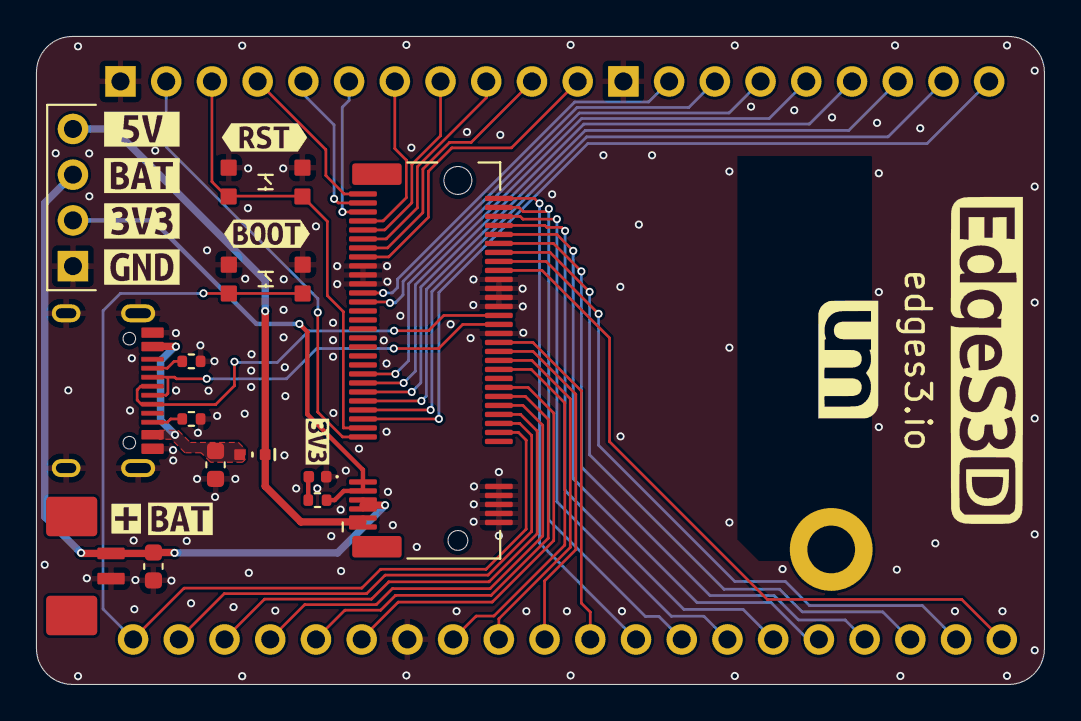
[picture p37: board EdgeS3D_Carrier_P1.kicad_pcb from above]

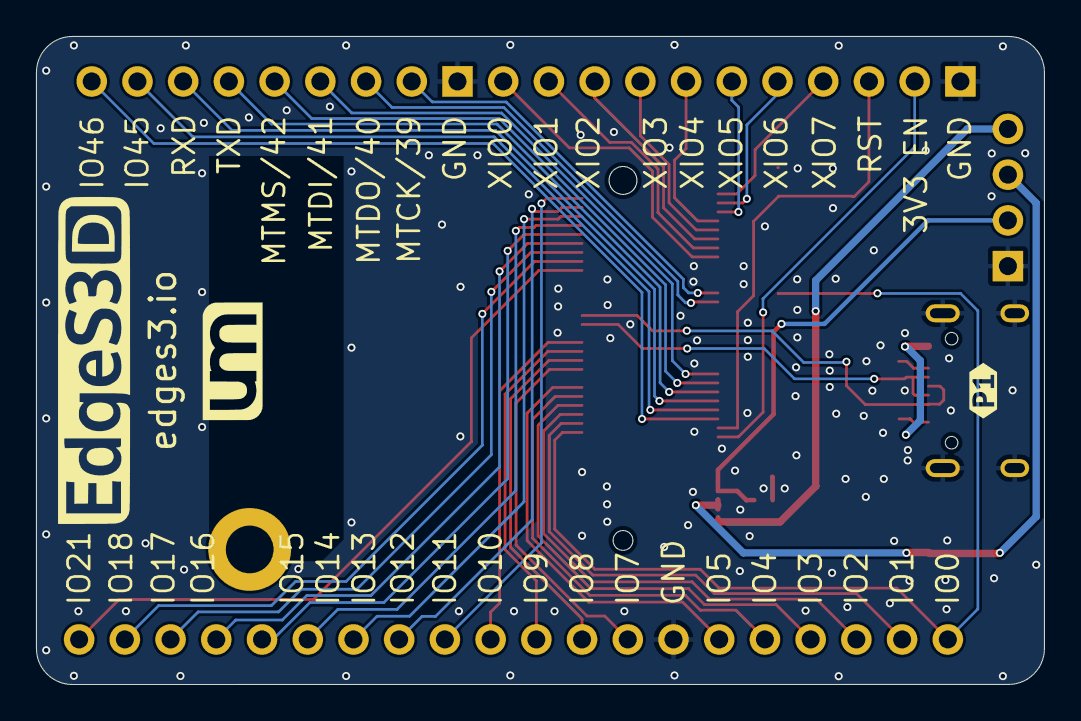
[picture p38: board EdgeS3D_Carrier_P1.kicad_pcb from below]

Board: 2 copper layers, 56.0 x 36.0 mm, 27 parts (2 on the bottom side), 47 nets.

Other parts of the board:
kibuzzard-66BFF55A: G***; kibuzzard-66BFF55A
kibuzzard-66BFF56B: G***; kibuzzard-66BFF56B
kibuzzard-66C05786: G***; kibuzzard-66C05786
kibuzzard-6857AC6A: G***; kibuzzard-6857AC6A
kibuzzard-6857AC7B: G***; kibuzzard-6857AC7B
kibuzzard-6857AC8E: G***; kibuzzard-6857AC8E
kibuzzard-6857AC89: G***; kibuzzard-6857AC89
kibuzzard-6857AD16: G***; kibuzzard-6857AD16
kibuzzard-6857ADA7: G***; kibuzzard-6857ADA7
kibuzzard-664315DB: G***; kibuzzard-664315DB

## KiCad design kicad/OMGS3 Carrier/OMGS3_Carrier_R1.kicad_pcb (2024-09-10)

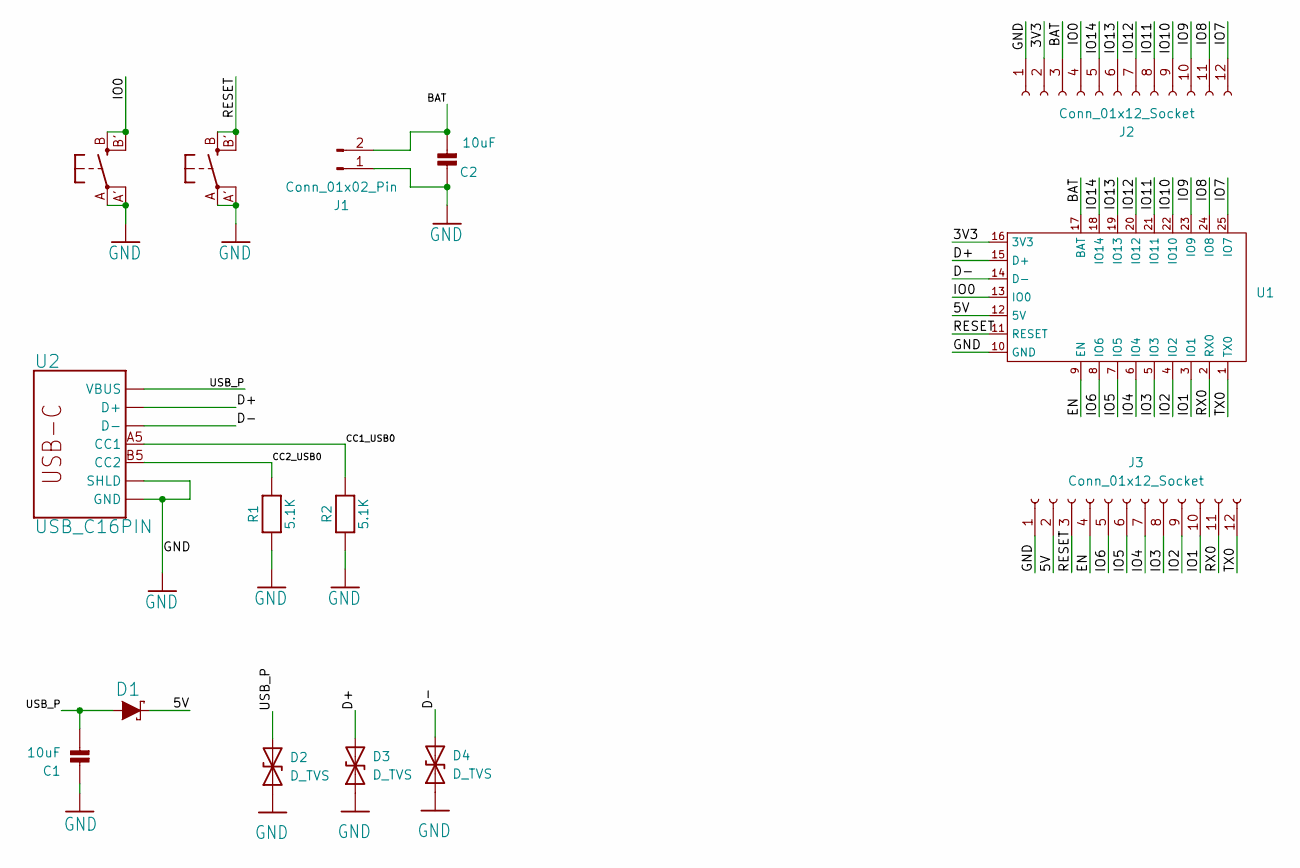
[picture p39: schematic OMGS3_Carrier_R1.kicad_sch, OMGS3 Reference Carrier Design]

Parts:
C1, C2: 10uF; C_0603_1608Metric
D1: DIODE-SCHOTTKYWIDE; SOD-523-MSK4010
D2, D3, D4: D_TVS; X1-DFN1006-2
J1: Conn_01x02_Pin; JST-PICOBLADE
J2, J3: Conn_01x12_Socket; PinHeader_1x12_P2.54mm_Vertical
R1, R2: 5.1K; R_0402_1005Metric
SW1, SW2: KMR2; BTN_KMR2_4.6X2.8
U1: OMGS3
U2: USB_C16PIN; USB-C-16P-LESSPASTE-2-Fixed-Sqr-Front

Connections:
/3V3: J2.2, U1.16 (3V3)
/5V: D1.C, J3.2, U1.12 (5V)
/BAT: C2.2, J1.2, J2.3, U1.17 (BAT)
/CC1_USB0: R2.2, U2.A5 (CC1)
/CC2_USB0: R1.2, U2.B5 (CC2)
/D+: D3.2 (A2), U1.15 (D+), U2.A6 (D+), U2.B6 (D+)
/D-: D4.2 (A2), U1.14 (D-), U2.A7 (D-), U2.B7 (D-)
/EN: J3.4, U1.9 (EN)
/IO0: J2.4, SW1.B (S), SW1.B' (S1), U1.13 (IO0)
/IO1: J3.10, U1.3 (IO1)
/IO2: J3.9, U1.4 (IO2)
/IO3: J3.8, U1.5 (IO3)
/IO4: J3.7, U1.6 (IO4)
/IO5: J3.6, U1.7 (IO5)
/IO6: J3.5, U1.8 (IO6)
/IO7: J2.12, U1.25 (IO7)
/IO8: J2.11, U1.24 (IO8)
/IO9: J2.10, U1.23 (IO9)
/IO10: J2.9, U1.22 (IO10)
/IO11: J2.8, U1.21 (IO11)
/IO12: J2.7, U1.20 (IO12)
/IO13: J2.6, U1.19 (IO13)
/IO14: J2.5, U1.18 (IO14)
/RESET: J3.3, SW2.B (S), SW2.B' (S1), U1.11 (RESET)
/RX0: J3.11, U1.2 (RX0)
/TX0: J3.12, U1.1 (TX0)
/USB_P: C1.2, D1.A, D2.2 (A2), U2.VBUS1 (VBUS), U2.VBUS2 (VBUS)
GND: C1.1, C2.1, D2.1 (A1), D3.1 (A1), D4.1 (A1), J1.1, J2.1, J3.1, R1.1, R2.1, SW1.A, SW1.A' (P1), SW2.A, SW2.A' (P1), U1.10 (GND), U1.EXP, U2.GND, U2.GND2 (GND), U2.SHLD, U2.SHLD1 (SHLD), U2.SHLD2 (SHLD), U2.SHLD3 (SHLD), U2.SHLD4 (SHLD), U2.SHLD5 (SHLD), U2.SHLD6 (SHLD), U2.SHLD7 (SHLD), U2.SHLD8 (SHLD)

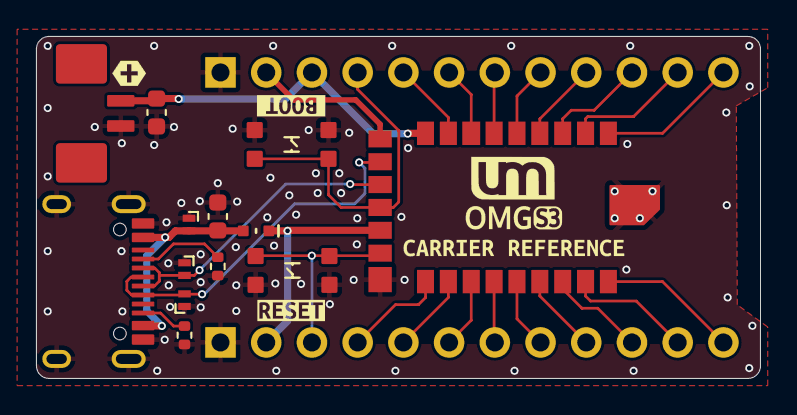
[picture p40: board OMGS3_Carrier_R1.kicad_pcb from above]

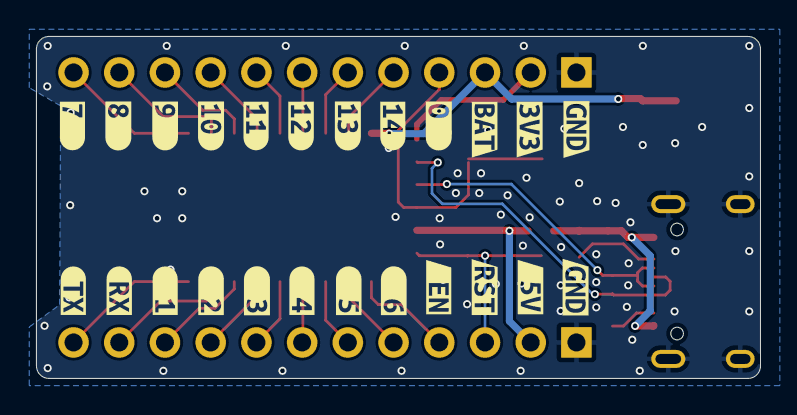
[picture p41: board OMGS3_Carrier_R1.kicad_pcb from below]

Board: 2 copper layers, 40.2 x 19.0 mm, 43 parts (24 on the bottom side), 28 nets.

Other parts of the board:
kibuzzard-66A337D7: G***; kibuzzard-66A337D7
kibuzzard-66A3379E: G***; kibuzzard-66A3379E
kibuzzard-66BFF9CC: G***; kibuzzard-66BFF9CC
kibuzzard-66BFF9DF: G***; kibuzzard-66BFF9DF
kibuzzard-66BFF9E6: G***; kibuzzard-66BFF9E6
kibuzzard-66BFF9F3: G***; kibuzzard-66BFF9F3
kibuzzard-66BFF9F9: G***; kibuzzard-66BFF9F9
kibuzzard-66BFF9FE: G***; kibuzzard-66BFF9FE
kibuzzard-66BFFA1D: G***; kibuzzard-66BFFA1D
kibuzzard-66BFFA03: G***; kibuzzard-66BFFA03
kibuzzard-66BFFA07: G***; kibuzzard-66BFFA07
kibuzzard-66BFFA15: G***; kibuzzard-66BFFA15
kibuzzard-66BFFA19: G***; kibuzzard-66BFFA19
kibuzzard-66BFFA21: G***; kibuzzard-66BFFA21
kibuzzard-66BFFAE0: G***; kibuzzard-66BFFAE0
kibuzzard-66BFFAF9: G***; kibuzzard-66BFFAF9
kibuzzard-66BFFB0C: G***; kibuzzard-66BFFB0C
kibuzzard-66BFFB4C: G***; kibuzzard-66BFFB4C
kibuzzard-66BFFB4F: G***; kibuzzard-66BFFB4F
kibuzzard-66BFFB5D: G***; kibuzzard-66BFFB5D
kibuzzard-66BFFB12: G***; kibuzzard-66BFFB12
kibuzzard-66BFFB21: G***; kibuzzard-66BFFB21
kibuzzard-66BFFB47: G***; kibuzzard-66BFFB47
kibuzzard-66BFFB52: G***; kibuzzard-66BFFB52
kibuzzard-66BFFB54: G***; kibuzzard-66BFFB54
kibuzzard-66BFFB58: G***; kibuzzard-66BFFB58
kibuzzard-66C531C2: G***; kibuzzard-66C531C2
kibuzzard-66C53217: G***; kibuzzard-66C53217

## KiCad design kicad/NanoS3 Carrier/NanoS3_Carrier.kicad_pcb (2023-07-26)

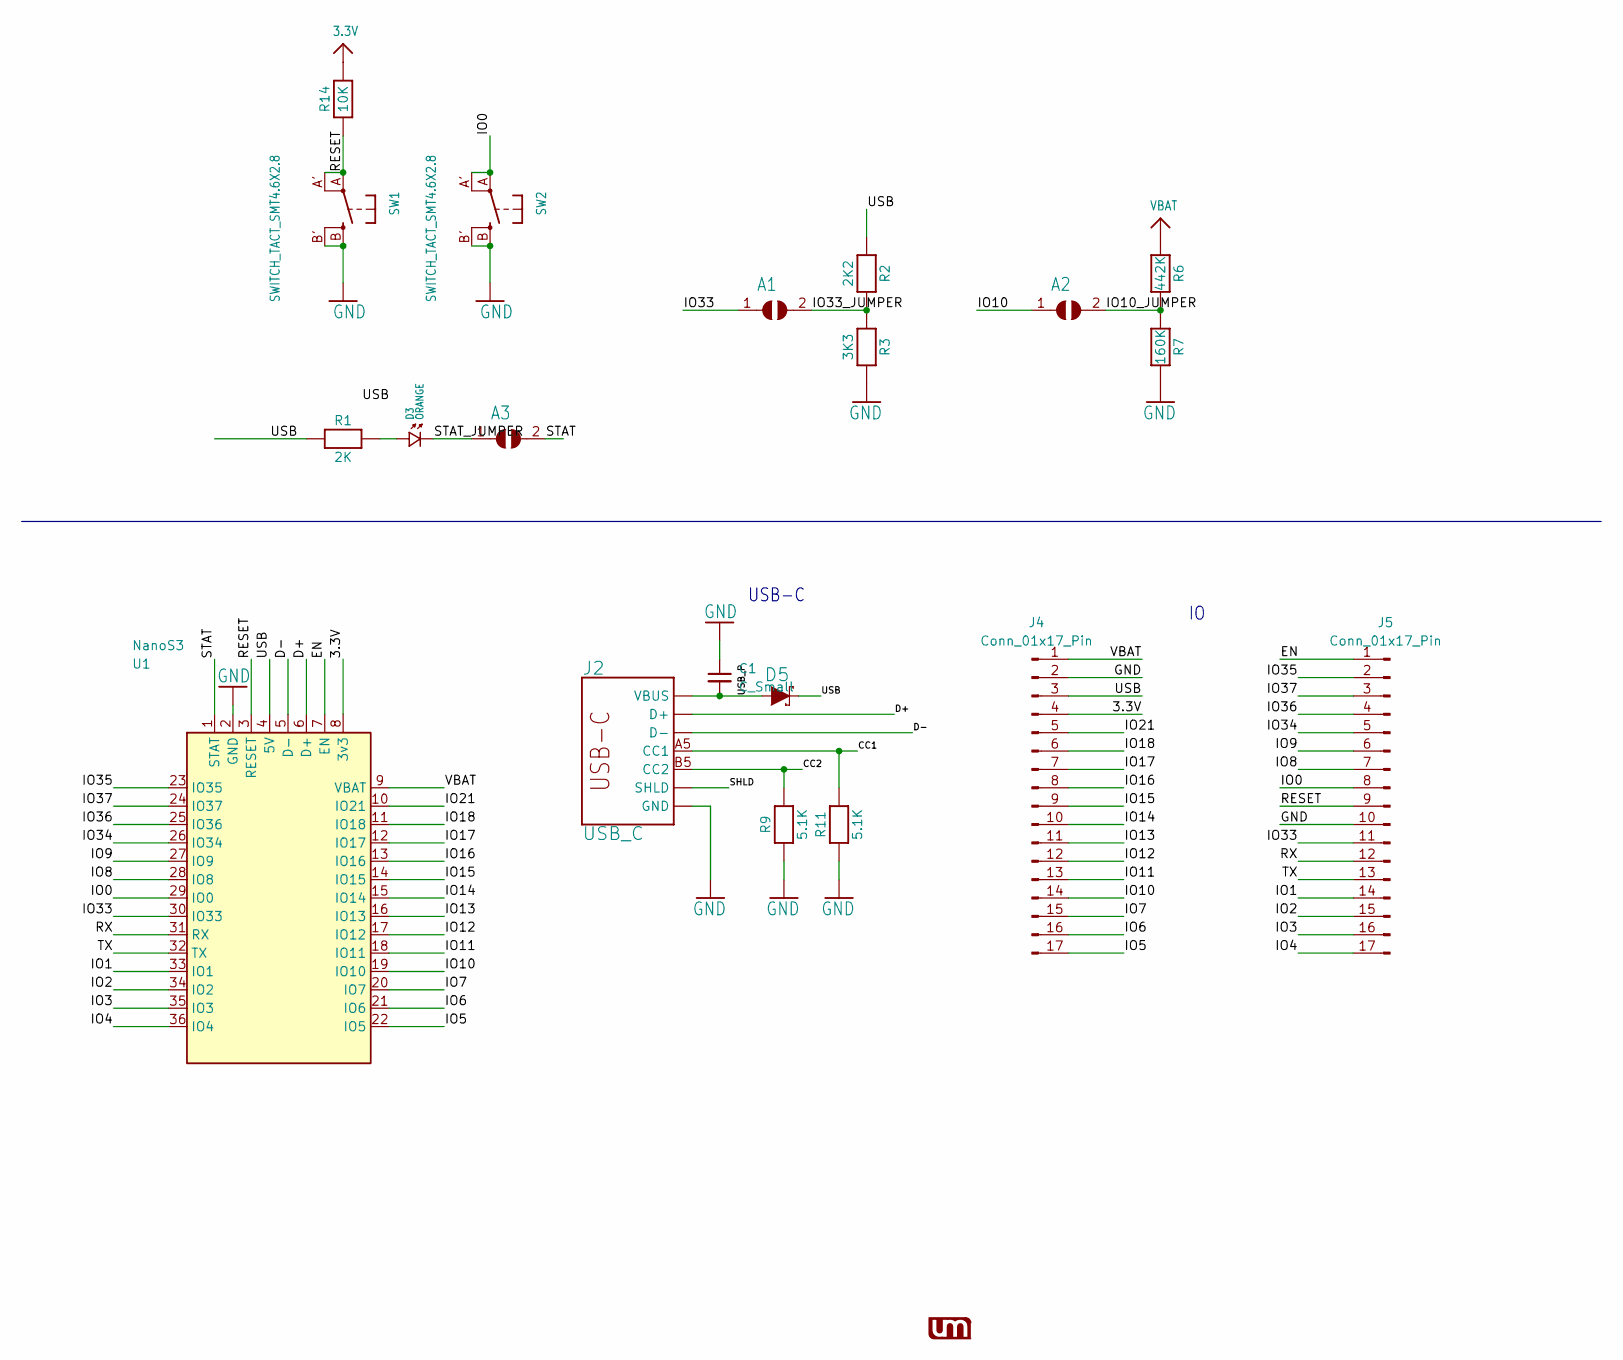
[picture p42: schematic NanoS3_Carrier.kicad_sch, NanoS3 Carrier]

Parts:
A1, A2, A3: SOLDERJUMPERCLOSED; SOLDERJUMPER_CLOSEDWIRE
C1: C_Small; C_0603_1608Metric
D3: ORANGE; 0402.LED.W
D5: DIODE-SCHOTTKYWIDE; SOD-523W
J2: USB_C; USB-C-16P-LESSPASTE-2-FIxed
J4, J5: Conn_01x17_Pin; 1X17_BLIZZARD_S3_BOTTOM
R1: 2K; _0402_SRWW
R2: 2K2; _0402_SRWW
R3: 3K3; _0402_SRWW
R6: 442K; _0402_SRWW
R7: 160K; _0402_SRWW
R9, R11: 5.1K; _0402_SRWW
R14: 10K; _0402_SRWW
SW1, SW2: SWITCH_TACT_SMT4.6X2.8; BTN_KMR2_4.6X2.8
U1: NanoS3
U$88: UM_LOGONEW_SMALLER; UM_LOGO_NEW_SMALLER

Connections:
3.3V: J4.4, R14.2, U1.8 (3v3)
/CC1: J2.A5 (CC1), R11.2
/CC2: J2.B5 (CC2), R9.2
/D+: J2.A6 (D+), J2.B6 (D+), U1.6 (D+)
/D-: J2.A7 (D-), J2.B7 (D-), U1.5 (D-)
/EN: J5.1, U1.7 (EN)
/IO0: J5.8, SW2.A, SW2.A' (P1), U1.29 (IO0)
/IO1: J5.14, U1.33 (IO1)
/IO2: J5.15, U1.34 (IO2)
/IO3: J5.16, U1.35 (IO3)
/IO4: J5.17, U1.36 (IO4)
/IO5: J4.17, U1.22 (IO5)
/IO6: J4.16, U1.21 (IO6)
/IO7: J4.15, U1.20 (IO7)
/IO8: J5.7, U1.28 (IO8)
/IO9: J5.6, U1.27 (IO9)
/IO10: A2.1, J4.14, U1.19 (IO10)
/IO10_JUMPER: A2.2, R6.2, R7.1
/IO11: J4.13, U1.18 (IO11)
/IO12: J4.12, U1.17 (IO12)
/IO13: J4.11, U1.16 (IO13)
/IO14: J4.10, U1.15 (IO14)
/IO15: J4.9, U1.14 (IO15)
/IO16: J4.8, U1.13 (IO16)
/IO17: J4.7, U1.12 (IO17)
/IO18: J4.6, U1.11 (IO18)
/IO21: J4.5, U1.10 (IO21)
/IO33: A1.1, J5.11, U1.30 (IO33)
/IO33_JUMPER: A1.2, R2.2, R3.1
/IO34: J5.5, U1.26 (IO34)
/IO35: J5.2, U1.23 (IO35)
/IO36: J5.4, U1.25 (IO36)
/IO37: J5.3, U1.24 (IO37)
/RESET: J5.9, R14.1, SW1.A, SW1.A' (P1), U1.3 (RESET)
/RX: J5.12, U1.31 (RX)
/STAT: A3.2, U1.1 (STAT)
/STAT_JUMPER: A3.1, D3.2
/TX: J5.13, U1.32 (TX)
/USB: D5.C, J4.3, R1.1, R2.1, U1.4 (5V)
/USB_P: C1.2, D5.A, J2.VBUS1 (VBUS), J2.VBUS2 (VBUS)
unnamed: D3.1, R1.2
VBAT: J4.1, R6.1, U1.9 (VBAT)

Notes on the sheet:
USB-C

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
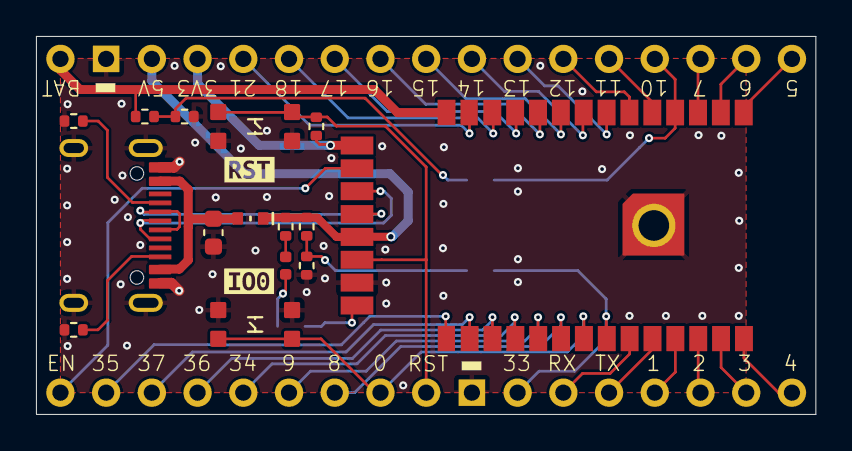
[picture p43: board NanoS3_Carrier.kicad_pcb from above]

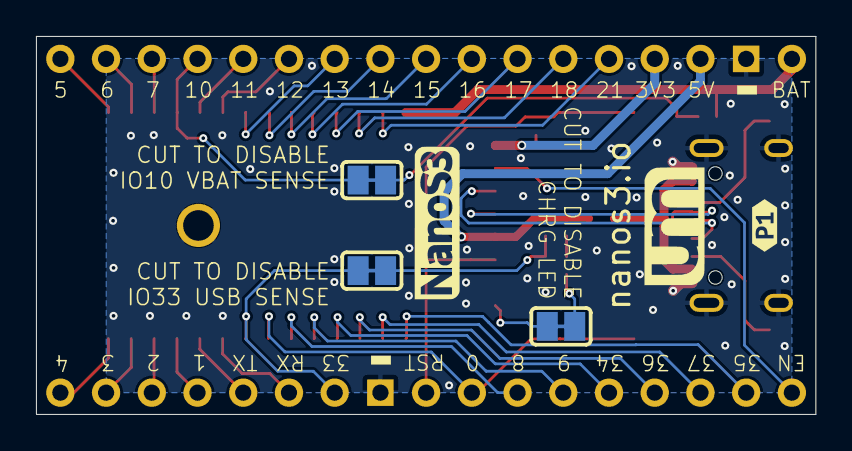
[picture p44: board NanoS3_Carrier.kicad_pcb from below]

Board: 2 copper layers, 43.3 x 21.0 mm, 24 parts (5 on the bottom side), 43 nets.

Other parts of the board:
kibuzzard-649F567F: G***; kibuzzard-649F567F
kibuzzard-649F677A: G***; kibuzzard-649F677A
kibuzzard-649F5696: G***; kibuzzard-649F5696

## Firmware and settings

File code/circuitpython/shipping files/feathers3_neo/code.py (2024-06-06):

# FeatherS3 Neo Shipping Demo
# 2024 Seon Rozenblum, Unexpected Maker
#
# Project home:
#   https://feathers3.io
#

import time, gc
from feathers3neo import FeatherS3NeoHelper, MatrixMessage, MatrixAnimation

helper = FeatherS3NeoHelper()
# Turn on the power to the NeoPixel matrix
helper.set_pixel_matrix_power(True)

# Say hello
print("\nHello from FeatherS3 Neo!")
print("-------------------------\n")

# Show available memory
print("Memory Info - gc.mem_free()")
print("---------------------------")
print(f"{gc.mem_free()} Bytes\n")

# Show flash size
# CircuitPython reserves a bunch of flash space for other features like OTA updates.
# If you would like to have access more of the 4MB of flash, you will need to compile
# your own CircuitPython firmware with a custom flash partition layout 
flash_size, flash_free = helper.flash_info
print("Flash - os.statvfs('/')")
print("---------------------------")
print(f"Partition Size: {flash_size} Bytes\nFree: {flash_free} Bytes\n")

# Get VBAT voltage
print("Approximate VBAT voltage")
print("------------------------")
print(f"{helper.battery_voltage}v\n")

# Check 5V Sense
print("Is 5V (VBUS) present?")
print("---------------------")
print(f"{helper.vbus_present}\n")

print("Pixel Time!\n")

# Create a color wheel index and a 
color_index = 0
# color time delay step
NEXT_COL = 0.01

# Initialise the matrix animation class, passing it the matrix, the animation shape name, and the trail length
# You can use this class to make pretty trail based shape animations
matrix_anim = MatrixAnimation(helper.matrix, 'spiral', 7)

# Initialise the matrix in Message mode, so you can display scrolling text on it
matrix = MatrixMessage(helper.matrix)

# Use get_characters() to build a message that shows every character in the font
# A great way to visualise al of the chars available
# message = matrix.get_characters()

message = "  Hello! "

# Set the scroll direction for the message
# valid directions are: direction LEFT, STATIC, RIGHT,
matrix.scroll_direction = matrix.LEFT

# Set the display rotation 
matrix.display_rotation = 0

# Setup the message, passing it the message, the scroll delay step in ms (default is 0.2) and if there should be padding between each character, or if they should butt up against eachother (default is True)
matrix.setup_message(message, delay=0.12, use_padding=True)

# Declare the R G B colors
r,g,b = 0,0,0

# Next colour step internal
next_color_step = 0.01

# Rainbow colors on the NeoPixel
while True:
    # Update the color from the color wheel every 10ms
    if time.monotonic() > NEXT_COL + next_color_step:
        color_index += 1
        # Get the R,G,B values of the next color
        r,g,b = helper.rgb_color_wheel( color_index )
        
        NEXT_COL = time.monotonic()

        # Set the color on the NeoPixel
        helper.pixel[0] = (r, g, b)
        
        # If the color_index is divisible by 100, flip the state of the blue LED on IO13
        if color_index % 100 == 0:
            helper.blue_led = not helper.blue_led
        
    # Show the message on the matrix if there is still something to show 
    if matrix.show_message(color=[r,g,b], brightness=0.2, fade_out=0.2):
        # We don't need to do anything here
        pass
    else:
        # Animate the RGB Matrix with the animation setup above
        matrix_anim.animate(r, g, b)
        # Sleep for 40ms so the animation cycle isn't too fast
        time.sleep(0.04)

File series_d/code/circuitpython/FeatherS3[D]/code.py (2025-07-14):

import time, gc, os
import neopixel
import board, digitalio
import feathers3d

# Create a NeoPixel instance
# Brightness of 0.3 is ample for the 1515 sized LED
pixel = neopixel.NeoPixel(board.NEOPIXEL, 1, brightness=0.3, auto_write=True, pixel_order=neopixel.RGB)

# Say hello
print("\nHello from feathers3d!")
print("------------------\n")

# Show available memory
print("Memory Info - gc.mem_free()")
print("---------------------------")
print("{} Bytes\n".format(gc.mem_free()))

flash = os.statvfs('/')
flash_size = flash[0] * flash[2]
flash_free = flash[0] * flash[3]
# Show flash size
print("Flash - os.statvfs('/')")
print("---------------------------")
print("Size: {} Bytes\nFree: {} Bytes\n".format(flash_size, flash_free))

print("Pixel Time!\n")

# Create a colour wheel index int
color_index = 0

# Turn on the power to the NeoPixel
feathers3d.set_ldo2_power(True)

# Rainbow colours on the NeoPixel
while True:
    # Get the R,G,B values of the next colour
    r,g,b = feathers3d.rgb_color_wheel( color_index )
    # Set the colour on the NeoPixel
    pixel[0] = ( r, g, b, 0.5)
    # Increase the wheel index
    color_index += 1

    # If the index == 255, loop it
    if color_index == 255:
        color_index = 0
        # Invert the internal LED state every half colour cycle
        feathers3d.led_blink()
        
    # Sleep for 15ms so the colour cycle isn't too fast
    time.sleep(0.015)
    

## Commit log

2022-02-03 Fixed some typos, thanks @mcauser
    [code.py, feathers3.py, pros3.py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]
2022-04-28 Added link to the Arduino Helper Library repository
2022-05-23 Fixed ProS3 symbol pin orientations
2022-08-06 Updated ProS3 and FeatherS3 schematics, fixing vertical STEMMA connector pin names
2022-12-24 Fixed incorrectly rotated pins on the TinyS3 and FeatherS3 KiCAD Symbol
2023-03-11 Updated FeatherS3 schematic for P7 to show new IO pins for I2C bus 2 on the vertical STEMMA/QT connector
2023-07-26 Added KiCAD 7 Footprint and Symbol for NanoS3
2023-07-26 Added KiCAD 7 NanoS3 Carrier Design Files
    [NanoS3_Carrier.kicad_pcb, NanoS3_Carrier.kicad_sch]
2023-07-27 Added NanoS3 Schematic
2023-07-29 Fixed incorrect NanoS3 KiCAD Symbol and added missing pinout card
2023-08-02 Updated other ESP32-S3 models
    [NanoS3_Carrier_Empty.STEP]
2023-08-02 Updated kicad folder
    [NanoS3_Carrier.kicad_pcb, NanoS3_Carrier.kicad_sch]
2024-02-08 Updated FeatherS3 pinout cards to include ADC info for VBAT Sense and AMB Light Sensor
2024-03-18 Fixed grid spacing for KiCAD Symbols
2024-06-06 Added FeatherS3 Neo files
    [FeatherS3Neo.step]
2024-06-06 Fixed FeatherS3 Neo schematic name
2024-06-30 Updated NanoS3 schematic to correct version
2024-08-18 Added OMGS3 files Added missing NanoS3 CP shipping files
    [OMGS3.step]
2024-09-07 Updated OMGS3 KiCAD Symbol and Footprint
2024-09-10 Added OMGS3 Carrier KiCAD Project Added STEP files for OMGUSB and OMG Carrier
    [OMGS3_Carrier.step, OMGS3_Carrier_R1.kicad_pcb, OMGS3_Carrier_R1.kicad_sch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]
2025-07-11 Added new Series[D] content
    [EdgeS3D.step, TinyS3D.step]
2025-07-12 Added EdgeS3[D] carrier reference kicad project and STEP file Updated EdgeS3[D] footprint and readme
    [EdgeS3D_Carrier_P1.kicad_pcb, EdgeS3D_Carrier_P1.kicad_sch]
2025-07-14 Added code folder with link to Arduino Series[D] helper Added CircuitPython shipping files
2025-07-15 Updated readme with more info and updated EdgeS3D.kicad_mod
2025-07-26 Fixed some wrong file names and updated NanoS3 Step
    [NanoS3 Castellated.step]
2025-10-06 Update platformio.ini
    Updated to use pioarduino to get latest ESP32 Arduino Core 3.x
2025-10-17 Added FeatherS3 P8 schematic
